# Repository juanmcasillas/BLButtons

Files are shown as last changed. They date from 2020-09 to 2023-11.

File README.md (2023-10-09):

# BLButtons
A simple, BLE Buttons controller to implement Simulator's button panels. Now supports multiple BLE profile,
you you map at the same time a Keyboard, a Gamepad and a Mouse.

Check this elements also:

* [ESP32-BLE-Combo](https://github.com/juanmcasillas/ESP32-BLE-Combo). Implements a multiple BLE profile, so you can send keyboard, mouse and gamepad (joystick) inputs as HID device.
* [BL-Radio](https://github.com/juanmcasillas/BLButtons/blob/master/RADIO.md). A custom made, generic radio panel (or whatever you want) to map the aircraft multiple radios interface. Implements modes and button remapping, as a bluetooth gamepad.
* [VoiceButtons](https://github.com/juanmcasillas/BLButtons/blob/master/voicebuttons/README.md). Map joystick inputs to text-to-speech commands. Works on Windows (Windows 10 tested) and includes a configuration file to tailor the app to your needs, and a DCS export module to extract data from it (so you can asign specific radio profiles por each mod (aka plane)). Very useful if you flight in VR and uses the `BL-Radio` radio panel.

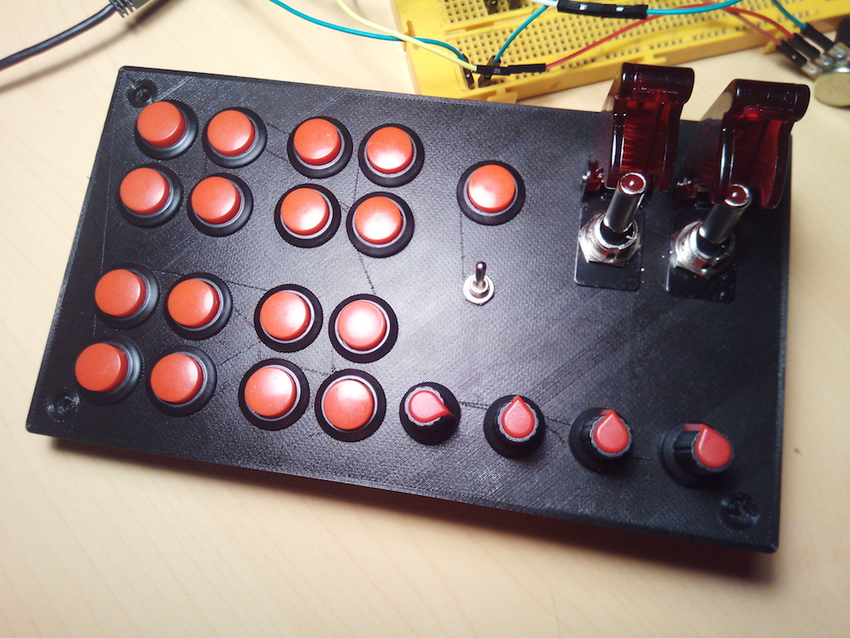
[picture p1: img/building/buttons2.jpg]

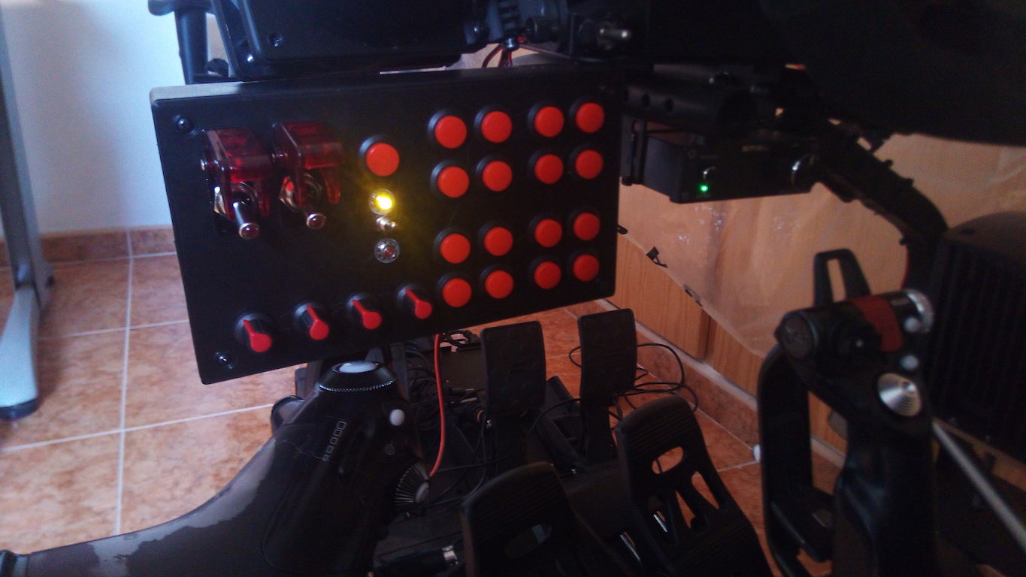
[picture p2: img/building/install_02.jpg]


# Table Of Contents

1. [Project Features](#project-features)

# Project Features

* Support clutch (2 modes).
* 4 axis x 3 = 12 axis (8 axis supported for Xinput).
* 17 buttons (x 2 modes) 51 buttons.
* 2 levers (two buttons) x 3 6 additional buttons.
* Pov hats are not in use.
* in clutch_mode == 2 (down), support for keyboard events (F1 ... F12) and mouse control.

* Changed the library [BLE Combo](https://github.com/Georgegipa/ESP32-BLE-Combo/) to support Gamepad. Use [My Fork](https://github.com/juanmcasillas/ESP32-BLE-Combo) in order to get the thing working.
## Arduino setup.

* Use [These drivers for the ESP32](https://www.silabs.com/developers/usb-to-uart-bridge-vcp-drivers?tab=downloads) on Win 10
* To upload, ensure the CLUTCH switch is on 0 (no light) or you can't upload the sketch.
* Use NodeMCU-32S (ESP32) board version to do the work

## ExceptionDecoder & SPIFFS Image Downloader

1. Go to [https://github.com/me-no-dev/EspExceptionDecoder/releases/](https://github.com/me-no-dev/EspExceptionDecoder/releases/) and download the latest release.
1. Go to [https://github.com/me-no-dev/arduino-esp32fs-plugin/releases/](https://github.com/me-no-dev/arduino-esp32fs-plugin/releases/) and download the latest release.
2. Go to the Arduino IDE directory, and open the `Tools` folder.
3. Unzip the downloaded .zip folders to the Tools folder. 
4. You should get something like `/Arduino-<version>/tools/ESP32FS/tool/esp32fs.jar` and the same for the exception decoder.

* [https://amstudioprojects.com/product/32-function-button-box-guide/](https://amstudioprojects.com/product/32-function-button-box-guide/)
* [https://www.instructables.com/id/Sim-Racing-Button-Box/](https://www.instructables.com/id/Sim-Racing-Button-Box/)
To use SPIFFS:

1. Inside the sketch folder, create a new folder called `data`
2. Inside the data folder is where you should put the files you want to be saved into the ESP32 filesystem.
3. Then, to upload the files, in the `Arduino IDE` you just need to go to `Tools > ESP32 Sketch Data Upload`.

Note: in some ESP32 development boards you need to keep the ESP32 on-board **`BOOT`** button pressed while it’s uploading the files. When you see the `Connecting …….____……` message, you need to press the ESP32 on-board **`BOOT`** button.

## BL gamepad library

0. Bounce2[https://github.com/thomasfredericks/Bounce2](https://github.com/thomasfredericks/Bounce2)
1. Go to [https://github.com/lemmingDev/ESP32-BLE-Gamepad/releases](https://github.com/lemmingDev/ESP32-BLE-Gamepad/releases) and download the latest release.
2. In the Arduino IDE go to `"Sketch" -> "Include Library" -> "Add .ZIP Library..."` and select the file you just downloaded.
3. You can now go to `"File" -> "Examples" -> "ESP32 BLE Gamepad"` and select the example to get started.
4. Updated to [https://github.com/MagnusThome/ESP32-BLE-Gamepad](https://github.com/MagnusThome/ESP32-BLE-Gamepad)
5. On laptop works properly.
6. A keypad Lib [https://github.com/Chris--A/Keypad](https://github.com/Chris--A/Keypad) for [The Example](https://github.com/MagnusThome/ESP32-BLE-Gamepad/blob/master/examples/5rotaryencoders_32buttons/5rotaryencoders_32buttons.ino)
7. Info about HID profile [https://eleccelerator.com/tutorial-about-usb-hid-report-descriptors/](https://eleccelerator.com/tutorial-about-usb-hid-report-descriptors/)
8. Official Nordic HID BLE [https://cdn.sparkfun.com/datasheets/Wireless/Bluetooth/RN-HID-User-Guide-v1.0r.pdf](https://cdn.sparkfun.com/datasheets/Wireless/Bluetooth/RN-HID-User-Guide-v1.0r.pdf)
9. Two profiles [https://www.esp32.com/viewtopic.php?t=10400](https://www.esp32.com/viewtopic.php?t=10400)
10. Keyboard HID profile [https://github.com/rupin/ESPJoystick/blob/master/gamepadble632/gamepadble632.ino](https://github.com/rupin/ESPJoystick/blob/master/gamepadble632/gamepadble632.ino)
11. USB HID definition tables [https://www.usb.org/hid](https://www.usb.org/hid)
12. USB HID usage tables [http://www.freebsddiary.org/APC/usb_hid_usages.php](http://www.freebsddiary.org/APC/usb_hid_usages.php)
13. More HID details [https://cdn.hackaday.io/files/18003770240352/HID.cpp](https://cdn.hackaday.io/files/18003770240352/HID.cpp)
14. Analog Smooth [https://github.com/MichaelThessel/arduino-analog-smooth](https://github.com/MichaelThessel/arduino-analog-smooth)
## Available PINOUTS

| GPIO | ADC  | INPUT | OUTPUT | NOTES |
|---|---|---|---|---:|
|0 x | 1/2  | pulled up | OK | Outputs PWM signal at boot |
|2 x | 2/2  | OK | OK | Connected to LED. LOW->LED Light  |
|4 x | 0/2  | OK | OK | |
|5 x | | OK | OK | Outputs PWM signal at boot |
|12 x | 5/2  | OK | OK | Boot fail if pulled HIGH |
|13 | 4/2  | OK | OK | Boot fail if pulled HIGH |
|14 x | 6/2  | OK | OK | Outputs PWM signal at boot |
|15 x | 2/2  | OK | OK | Outputs PWM signal at boot |
|16 x | | -- | -- | used on ESP-32_WROVER_KIT ** |
|17 x | | OK | OK | used on ESP-32_WROVER_KIT |
|18 x | | OK | OK | |
|19 x | | OK | OK | |
|21 | | OK | OK | |
|22 | | OK | OK | |
|23 | | OK | OK | |
|25 | 8/2  | OK | OK | |
|26 x | 9/2  | OK | OK | |
|27 x | 7/2  | OK | OK | |
|32 x | 4/1  | OK | OK | |
|33 x | 5/1  | OK | OK | |
|34 x | 6/1  | OK | | Input Only |
|35 x | 7/1  | OK | | Input Only |

* PIN16 on new version, doesn't work. Changed with PIN13
* ADC Column: ADC Channel/ADC1|ADC2. No number means no ADC.
* ADC2 pins cannot be used when Wi-Fi is used. 
* The ADC input channels have a 12 bit resolution. 
* This means that you can get analog readings ranging from 0 to 4095, in which 0 corresponds to 0V and 4095 to 3.3V. 
* ANALOG INPUTS: 14 . 10 on ADC2, 4 on ADC1 (usable with WIFI)
* DIGITAL INPUTS: 21 TOTAL, 7 only DIGITAL. Be careful with 12 and 13

* ANALOG -> 3 [18]
* KEYPAD -> 7x7 [14] [49 buttons] 
* Clutch -> 1 dedicated line (to avoid ghosting on the matrix - no use diodes)

## First Prototype

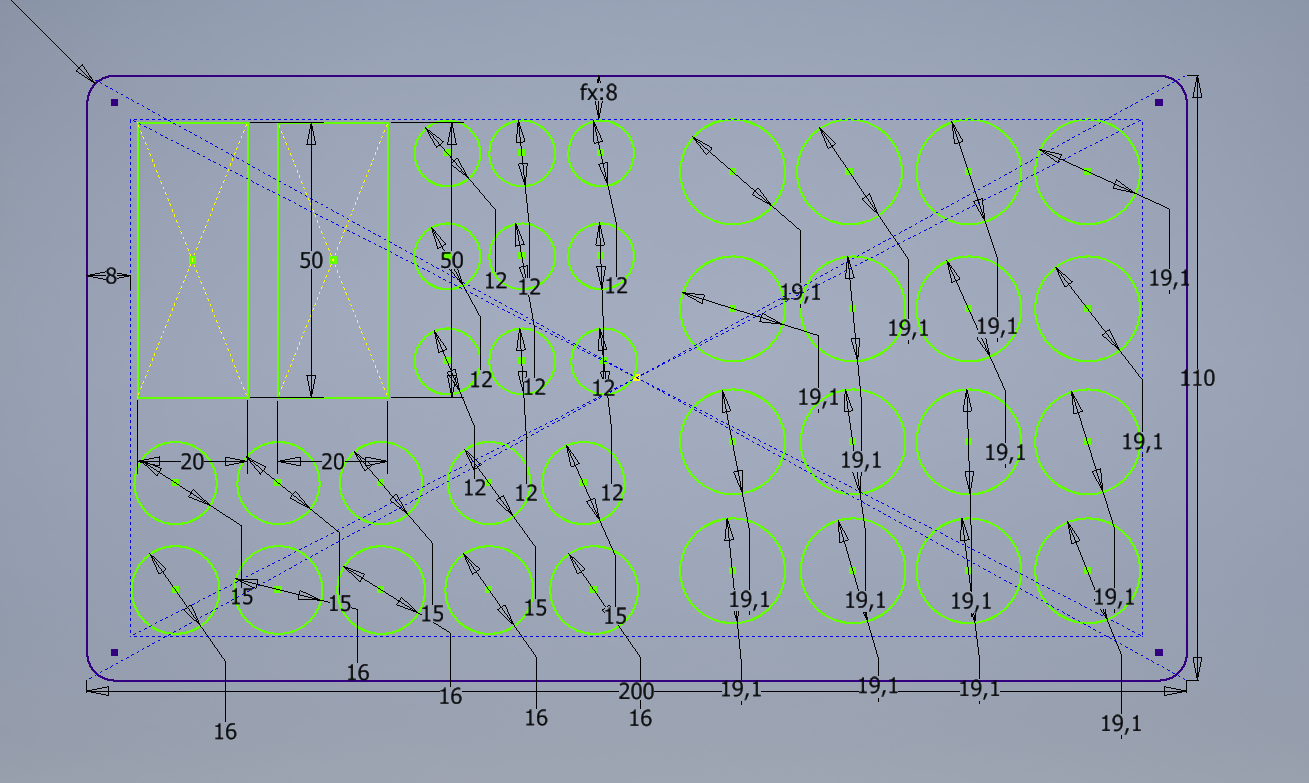
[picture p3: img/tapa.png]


```

| ITEM  |   QUANTITY    | PINS  | TOTAL PINS |
|-------|---------------|-------|-----------:|
|LEVC   | 2             | 1     |          2 |
|LEV    | 9             | 2     |         18 |
|BUT    | 16            | 1     |         16 |
|ENC    | 5             | 3     |         15 | 
|POT    | 5             | 1     |          5 |
|-------|---------------|-------|-----------:|
| TOTAL |               |       |  56 (51+5) |       
|-------|---------------|-------|-----------:|

MAX: 21 INPUTS

Clutch LEFT (+1 Digital) 57 (52+5)
ENC->Really are:
2 for DT*CLK signal
1 for SWITCH (serial plug)

-> More push buttons
-> Less Lever
-> Less Rotary (eats 3 pins per rotary)
*****Confirm these values****
Better more push buttons? (24)

4 pot (axis)    (21-4=17) [better 4 and leave the wifi alone]
4x4 = 16 buttons (17-(4+4)=9)
2LEVC (9-2=7)
CLUTCH (7-2=5)
2LEV (5-4=1)
1 free XD

| PIN   | TO                    | NOTES                |
|-------|-----------------------|---------------------:|
| 14    | COL_0                 | Boot Fail if HIGH    |
| 27    | COL_1                 |                      |
| 26    | COL_2                 |                      |
| 25    | COL_3                 |                      |
|-------|-----------------------|----------------------|
| 33    | POT_1 (leftmost)      | CH_4 ADC1 together   |
| 32    | POT_2                 | CH_5 ADC1            |
| 35    | POT_3                 | CH_6 ADC1            |
| 34    | POT_4 (rightmost)     | CH_7 ADC1            |
|-------|-----------------------|----------------------|
| 15    | CLUTCH_1              |                      |
| 2     | CLUTCH_2              | low or won't flash   |
|-------|-----------------------|----------------------|
| 4     | ROW_0                 | Pulled up            |
| 13    | ROW_1                 | Connected to LED (*) |
| 17    | ROW_2                 |                      |
| 5     | ROW_3                 | Boot Fail if HIGH    |
|-------|-----------------------|----------------------|
| 18    | LEVER_COVER_1         |                      |
|-------|-----------------------|----------------------|
| 19    | LEVER_COVER_2         |                      |
|-------|-----------------------|----------------------|
| 21    | BUTTON_1              |                      |
|-------|-----------------------|----------------------|
| 0     | free pins             | not use              |
| 2     |                       |                      | 
| 16    | in new version, fails | (*) changed with 13  |
| 22    |                       |                      |
| 23    |                       |                      |
|-------|-----------------------|----------------------|

Led Wiring: 300 OHMs resistor

MAX 32 inputs !!!
16 + 2 + 2 + 2 = 22 + 4 axis

CLUTCH mode:
    16 buttons x 2 = 32 inputs
    
BOX: 200x110x65
Lever: 74 x 54 x 12 mm
Lever_Cover: 60 x 130 x 40 mm

ENC:    15
POT:    16x25
BUT:    19
LEVC:   20x50
LEV:    12
```

## IL2 Minimum Controls

### Joystick 

Engine Start
Water Radiators 
Oil Radiators
Wheel Brake
Inlet/Outlet Cowls
Mixture
RPM lever (Prop pitch)
Flaps
Landing Gear
Open/Close Canopy
Open/Close Bomb Bay Doors
Airbrakes
Mission Brief Screen
Engine Boost
Fire Guns/Cannons/Missiles/Bombs
Auto Level
Field of view zoom in
Field of view zoom out
Recenter Track IR
Eject

### Keyboard

Nav Lights
Instrument Lights
Super Charger Stage Toggle
Engine Select

### The BLE profile (this has been changed due the combo mode)

```
 0x05, 0x01,              // USAGE_PAGE (Generic Desktop)
    0x09, 0x04,              // USAGE (Joystick)
    0xa1, 0x01,              // COLLECTION (Application)
    0x85, 0x03,              // REPORT_ID (3)
    0xa1, 0x00,              // COLLECTION (Physical)
    
    0x05, 0x09,              // USAGE_PAGE (Button)
    0x19, 0x01,              // USAGE_MINIMUM (Button 1)
    0x29, 0x40,              // USAGE_MAXIMUM (Button 64)
    0x15, 0x00,              // LOGICAL_MINIMUM (0)
    0x25, 0x01,              // LOGICAL_MAXIMUM (1)
    0x75, 0x01,              // REPORT_SIZE (1)
    0x95, 0x40,              // REPORT_COUNT (64)
    0x81, 0x02,              // INPUT (Data,Var,Abs)
    
    0xc0,               // END_COLLECTION
    0xc0               // END_COLLECTION
```

```
exports.report = new Uint8Array([
  0x05,   0x01,                    // USAGE_PAGE (Generic Desktop)
  0x09,   0x05,                    // USAGE (Game Pad) - Hut1_12v2.pdf p28 of 128
  0xA1,   0x01,                    // COLLECTION (Application)

  0xA1,   0x00,                    //   COLLECTION (Physical)
  0x05,   0x09,                    //     USAGE_PAGE (Button)
  0x19,   0x01,                    //     USAGE_MINIMUM (Button 1)
  0x29,   0x10,                    //     USAGE_MAXIMUM (Button 16)

  0x15,   0x00,                    //     LOGICAL_MINIMUM (0)
  0x25,   0x01,                    //     LOGICAL_MAXIMUM (1)
  0x95,   0x10,                    //     REPORT_COUNT (16)
  0x75,   0x01,                    //     REPORT_SIZE (1)

  0x81,   0x02,                    //     INPUT (Data,Var,Abs)

  0x05,   0x01,                    //     USAGE_PAGE (Generic Desktop)
  0x09,   0x30,                    //     USAGE (X)
  0x09,   0x31,                    //     USAGE (Y)
  0x09,   0x32,                    //     USAGE (Z) - Hut1_12v2.pdf p26 = represents R X-axis
  0x09,   0x33,                    //     USAGE (Rx) - Hut1_12v2.pdf p26 = represents R Y-axis

  0x15,   0x81,                    //     LOGICAL_MINIMUM (-127)
  0x25,   0x7F,                    //     LOGICAL_MAXIMUM (127)
  0x75,   0x08,                    //     REPORT_SIZE (8)
  0x95,   0x04,                    //     REPORT_COUNT (4)

  0x81,   0x06,                    //     INPUT (Data,Var,Abs) - absolute for joysticks ( != rel for mouse )
  0xC0,                            //   END_COLLECTION

  0xc0 ]                           // END_COLLECTION
);
```

NANO SERIAL: Solved using ATmega328P (Old Bootloader)...

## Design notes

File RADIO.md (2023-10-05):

# BL-Radio

Implement a generic radio control panel for DCS. Support multiple profiles, button mapping, and works as BLE wireless gamepad device. Now, support sending keypresses based on button mapping. The rationale is the OBS studio doesn't work
with DirectInput, so you can't map commands (start record, end record) to buttons what it's a pain. So due the the 
BLE combo stack supports multiple devices (keyboard, keypad, and mouse) I manage to double some buttons as keyboard
keypresses. if `KEYBOARD_CHORD` is defined, `KEY_RIGHT_ALT + KEY_RIGHT_CTRL` is also send to avoid keyboard collision.
see `KEYBOARD_MAP` array to map the desired keypresses to the buttons (keypress definitions are stored on `BleKeyboard.h`)

```
NANO 2W switches (top switches ath the sides of the selector box)

SW2_1_S1 ----> button 11 ---> Also doubles as keypress KEY_RIGHT_ALT + KEY_RIGHT_CTRL + KEYPAD_DIVIDE   (/ in keypad)
SW2_1_S2 ----> button 12 ---> Also doubles as keypress KEY_RIGHT_ALT + KEY_RIGHT_CTRL + KEYPAD_MULTIPLY (* in keypad)
SW2_2_S1 ----> button 13 ---> Also doubles as keypress KEY_RIGHT_ALT + KEY_RIGHT_CTRL + KEYPAD_SUBTRACT (- in keypad)
SW2_2_S2 ----> button 14 ---> Also doubles as keypress KEY_RIGHT_ALT + KEY_RIGHT_CTRL + KEYPAD_ADD      (+ in keypad)
```

<center>
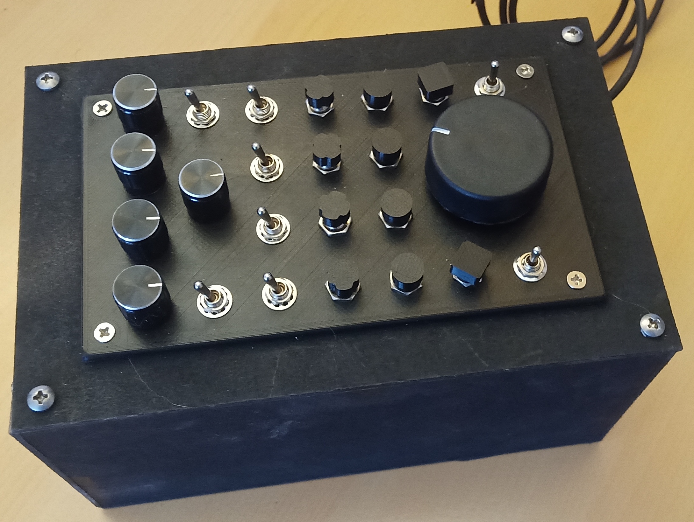
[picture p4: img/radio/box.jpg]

</br>
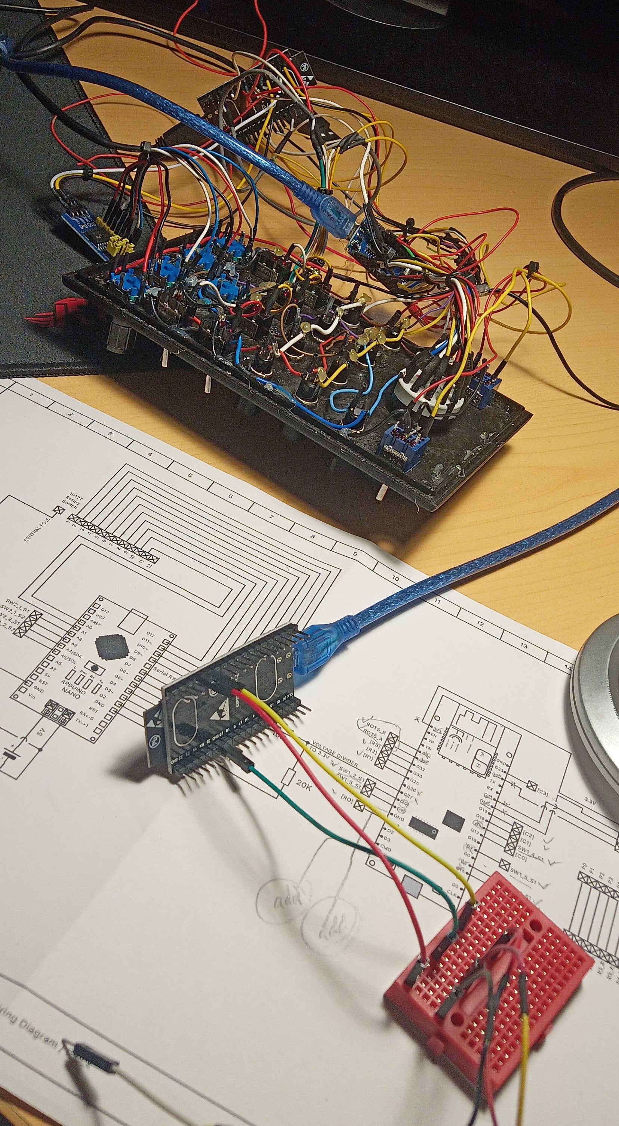
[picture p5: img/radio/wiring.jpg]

</center>

<center>
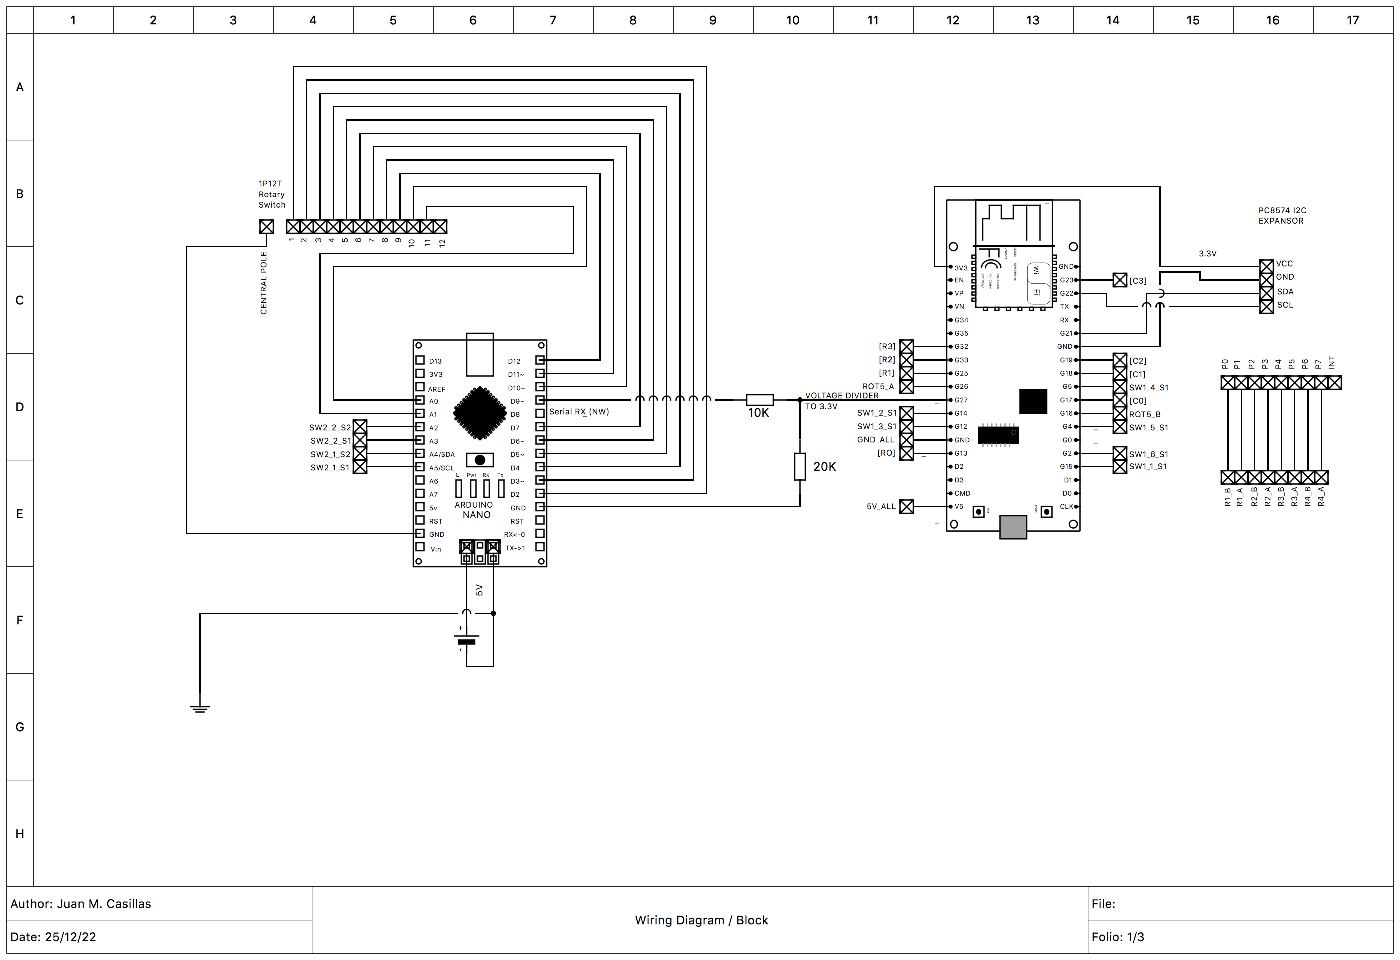
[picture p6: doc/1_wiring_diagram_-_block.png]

</br>
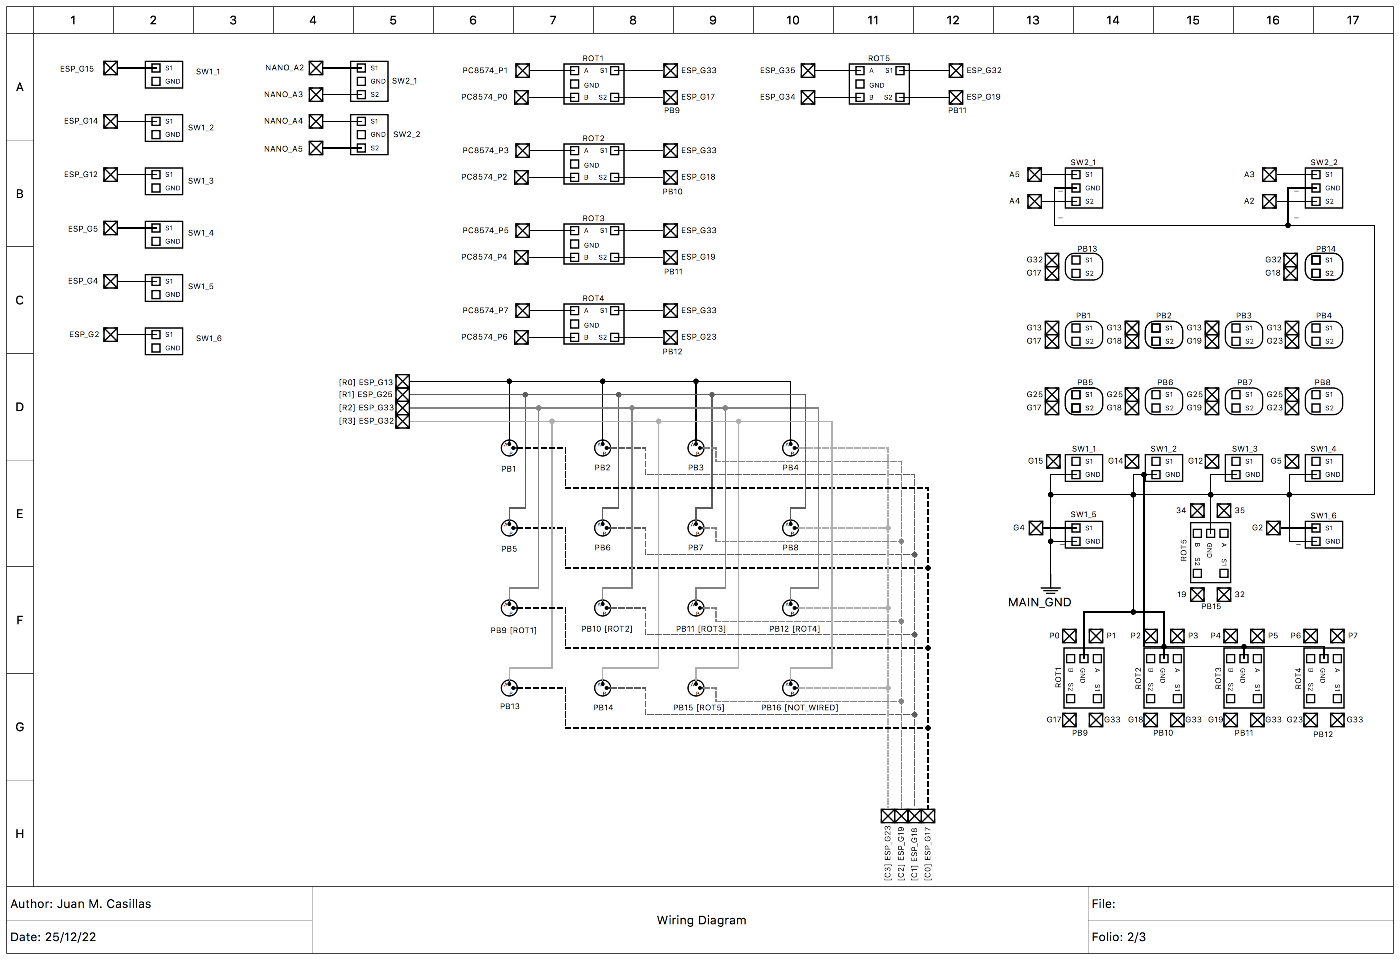
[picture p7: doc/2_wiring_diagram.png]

</br>
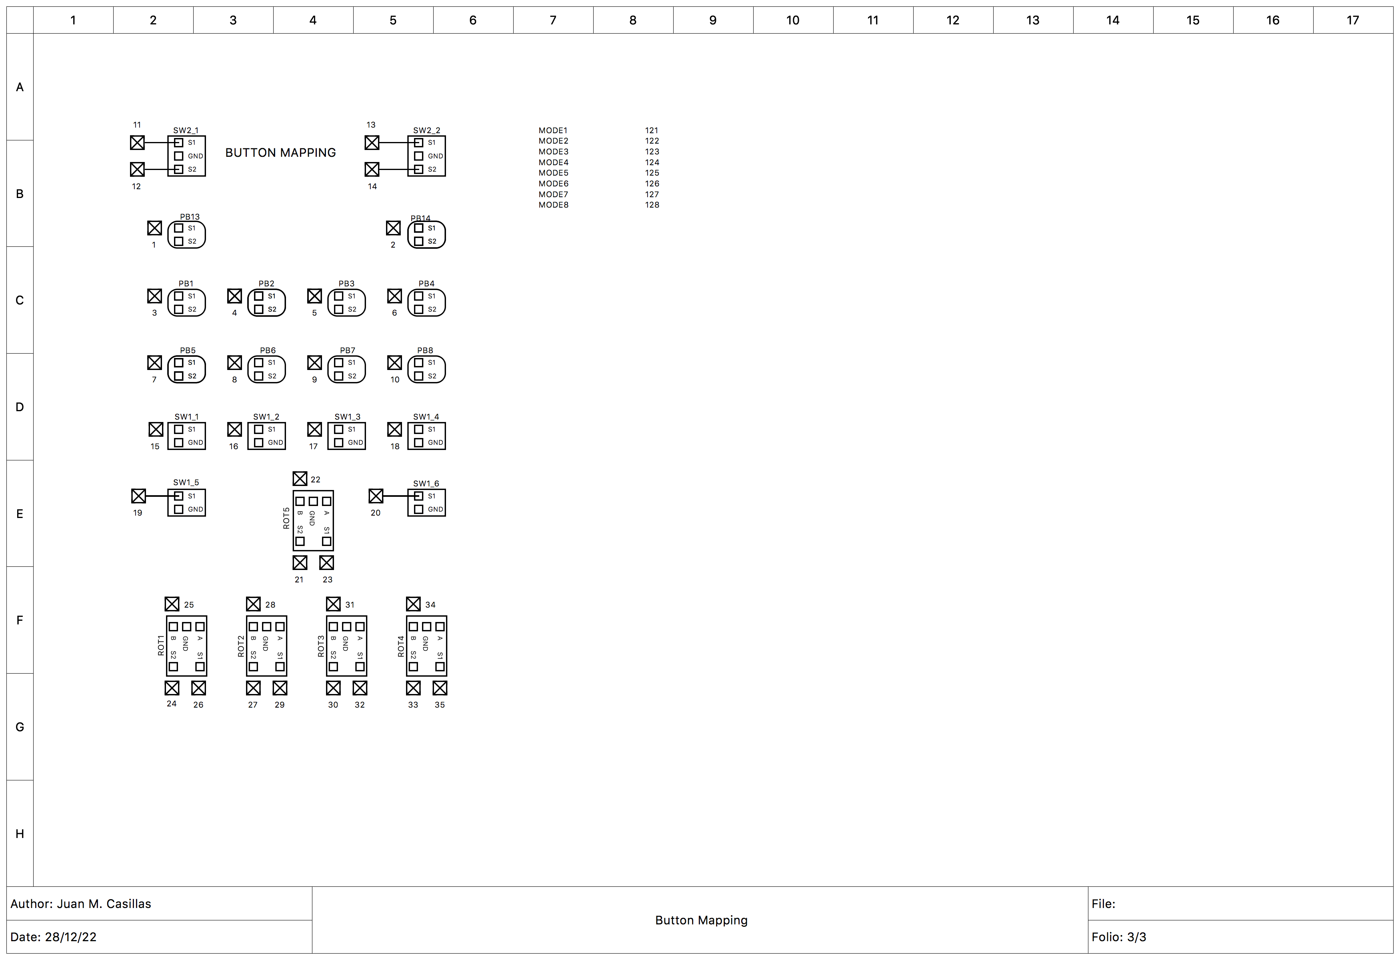
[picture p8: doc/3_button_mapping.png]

</center>

# 3D Printing files:

* <a href="stl/radio/tapa_radio.stl">Box Cover</a>
* <a href="stl/radio/button_round.stl">Button Round</a>
* <a href="stl/radio/button_square.stl">Button Square</a>
* <a href="stl/radio/button_round_variant.stl">Button Round (variant)</a>
* <a href="stl/radio/button_square_variant.stl">Button Square (variant)</a>

# Requirements

```
Lights:

   - taxi lights (left, right)
   - nav lights 
   - landing lights (left, right)
   - anti collision lights
   - formation lights
    
    - internal lights
    - dim 
    - center console
    - instruments
    - left console
    - right console
    - storm lights

F5
AN/ARC-164 UHF
    1 selector for channel preset
    5 selector for radio frequency tunning knobs
    1 mode (off, main, both, adf)
    1 freq mode (manual, preset, guard)
    1 selector antena (upper, auto, lower)

TACAN
    2 tunning knobs
    1 tacan mode: (off, t/r, a/a rec a/a t/r)
    1 nav_mode (df, tacan)

HSI
    1 knob for HDG
    1 knob for CRS

C101
ADF
    1 selector NAV/ADF (HSI)
    1 transfer button (to select adf1, adf2)
    3 kobs for ADF tunning
    1 selector for mode (off, ant, adf, test)
VOR (VHF-NAV)
    1 knob for tunning
    1 selector for mode (off, nav, stdby, dme, guard)
    1 selector antena (upper, auto, lower)
    1 dme hold or norm
VOR (ILS/AN/ARN-127)
    1 VHF 10 position selector (KHz) 105-117
    1 VHF 10 position selector (KHz) 0-9
    1 VHF 2 position selector (KHz) 00,05,

Huey
UHF AN/ARC-51BX (AA comms most used)
    1 function (off, t/r, t/r+g, adf)
    1 man/preset/gd-xmit
    1 select channel (1-20)
    3 dial knobs

VHF AN/ARC-134 (AA and Tower)
    1 function (off, power, test)
    2 dial knobs

FM AN/ARC-131 internal flight comms, ground homing
    1 function (off, t/r, retran,  home)
    4 dial knobs

AN/ARN-82 Radio Nav Panel
    1 selector (ADF, VOR)

AN/AR-83 ADF
    1 selector (off, adf, ant, loop)
    1 adf loop (left, right)
    1 bfo (on, off)
    1 adf band selector (3 pos)
    1 tunning knob
    1 adf gain
```

```
Pro MICRO inputs

ENCODERS:
    CLK         2x encoder D2/D3 se supone que se puede meter en un keypad.
    DT          
    SW          to the KEYPAD (button) + GND
    VCC (+)     common
    GND         common

5 encoders:
    2 (CLK,DT) x 5 = 10 signals + 5 SW = 15 (4x4) = 16 inputs. left 1.

Selectors & switches.
    3 position
    1 radio selector 8 pos (better 6)
    7 ?

Resume:

ENCODERS:
2 PINs PER encoder: 8 PINS for input encoding.

Encoders:                            =  4 + 8 PINS.
Encoder 1P12T using 12T              = 12
5 three way switch (using 2)         = 10            (10)
5 two way switch (using 1)           =  5            (7)
5 buttons                            =  5            (5 black, 5 red)
TOTAL                                = 36 input.

6x6 = 36 matrix.

Buttons:
  Encoders: 3 * 4 =       12
  3-way: 5 x 2 =          10
  2-way: 5 x 1 =           5
  5 buttons: 5 x 1 =       5
  TOTAL                   32 buttons.
  Modes (12): 12 x 32=    384 buttons (3x128 buttons) (gamepad device with 3 pages ? XD)

https://github.com/RobTillaart/PCF8574/issues/27

3 x 3 -> 9 buttons (5 buttons + 4 encoders)

1 expansor para los switches de 3 vias (8 inputs) 0x1
1 expansor para los switches de 2 vias + 1 de tres vias (8 inputs) 0x2
1 expansor para los encoders (4 * 2) 8 inputs.
2 + 6 = 8 PINS.
```

| PIN | TO | NOTES |
|---|---|---:|
Button matrix: 9 values, 3x3 matrix
| 13    | COL_0                 |                      |
| 14    | COL_1                 | Boot Fail if HIGH    |
| 27    | COL_2                 |                      |
| 26    | ROW_0                 |                      |
| 25    | ROW_1                 |                      |
| 33    | ROW_2                 | CH_4 ADC1 together   |
| MODE_SELECTOR = 12 values, 3x4 matrix
| 4     | ROW_0                 | Pulled up            |
| 16    | ROW_1                 | Connected to LED     |
| 17    | ROW_2                 |                      |
| 18    | COL_0                 |                      |
| 19    | COL_1                 |                      |
| 23    | COL_2                 |                      |
| 32    | COL_3                 | CH_5 ADC1            |
| maybe use the 5th element.
| 15    | ENCODER_5 SW          |                      |
| 34    | ENCODER_5 DT          | CH_7 ADC1 only IN    | 
| 35    | ENCODER_5 CLK         | CH_6 ADC1 only IN    |
| --
| 21    | SDA                   |                      |
| 22    | SCL                   |                      |
| --
| 2     |                       | low or won't flash   | 
| 5     |                       | Boot Fail if HIGH    |
| 12    |                       |                      | 
| --
|       | free pins             |                      |
| --
| --
| 0     |                       | not use              |
| --

```
LAST CALCULATION.
Buttons must be momentary in order to work with the KEYPAD.

So:
  Mode selector: 12 input keypadtrix 3*4 = 12 signals. (7 GPIO)
  5 3-way: (10 signals, using 8 in one expansor I2C using 2 in the other expansor.
  6 2-way: (6 signals, using 6 in the second expansor)
  5 encoders: 
        - 1x4 signals in a keypad arrangement of 3x3 GPIO (6 GPIO) 
        - 2x4 signals in the third expansor (8 signals)

        - 1x1 signal in the GPIO 2 (SW)
        - 2x1 signals in GPIO5, and 12.

TOTALS:
  1x  Mode:           12 signals, 4x3, 7 GPIO.
  5x  3-way:          10 signals, 2 GPIO (SCL,SDA)
  6x  2-way:           6 signals
  5x  encoders: SW:    4 signals in the keypad button, 3x3, 6 GPIO
             CLK/DT    8 signals in the third expansor
             SW:       1 signal on GPIO2
             CLK/DT    2 signals on GPIO5, GPIO12
  5x buttons:          5 signals in the keypad button.
```

## after implementing the Serial bridge between Arduino Nano & ESP32

```
So:
  Mode selector: 12 Signals from 15 available using GPIO27,GPIO26 [3 available, frees 4 GPIO[4,16,17,18,19,23,32], used on Serial]
  5 3-way: (10 signals, using 8 in one expansor I2C using 2 in the other expansor.
  6 2-way: (6 signals, using 6 in the second expansor)
  6 encoders: 
        - 1x6 signals in a keypad arrangement of 4x4 
        - 2x4 signals in the third expansor (8 signals) CLK/DT
        - 4x1 signals in GPIO5, GPIO12, 

  1x  Mode:           12 signals, 2 GPIO [Serial]
  6x  3-way:          10 signals, 2 GPIO (SCL,SDA)
                       2 signals, 2 GPIO [Serial]
  6x  2-way:           6 signals
  6x  encoders: SW:       6 signals in the keypad button, 4x4, 8 GPIO
                CLK/DT    8 signals in the third expansor (SCL,SDA)
                CLK/DT    2 signals on GPIO5, GPIO12
                CLK/DT    2 signals on GPI23, GPIO32
  6x buttons:          6 signals in the keypad button.

                       ?? 1 signal 2 GPIO available [Serial]
                       ?? 4 signal available on keypad.
  4 free gpios mean instead 3x3 (9) 4x4 (16) -> 7 more buttons !!! [13,14]
```

## After getting al the components:

| PIN | TO | NOTES |
|---|---|---:|
| Button matrix: 16 values, 4x4 matrix
| 13 | ROW_0 | |
| 25 | ROW_1 | |
| 33 | ROW_2 | CH_4 ADC1 together |
| 32 | ROW_3 | CH_5 ADC1 |
| 17 | COL_0 | |
| 18 | COL_1 | |
| 19 | COL_2 | |
| 23 | COL_3 | |
| MODE_SELECTOR = 12 values, 12 signals, 2 GPIO [Serial]
| 27 | RX | |
| 26 | TX | |
| Expansors I2C
| 21 | SDA | |
| 22 | SCL | |
| 2 |  2W | low or won't flash | 
| 4 |  2W | Pulled up |
| 5 |  2W | Boot Fail if HIGH |
| 12 |  2W | cant be pulled HIGH  | 
| 14 |  2W | Boot Fail if HIGH |
| 15 |  2W | |
| Extra encoders 
| 34 | | CH_7 ADC1 only IN | 
| 35 | | CH_6 ADC1 only IN |
| free pins
| 0 | | not use |
| maybe use the 5th element.
| 16 | 2W | Connected to LED |

```
  Mode selector: 11 Signals from 15 available using GPIO27,GPIO26Serial]
  2 3-way in nano. (4 signals) [only 2 values]
  6 2-way ESP32 [2,4,5,12,14,15]
  4 encoders in the expansor (8 signals)
  1 encoder in ESP32 [34,35]

  5 buttons from encoders [left 11 buttons]
  6 push buttons [on keypad matrix]
  
  Rotary encoder
  
   CW
 (right)  
    ^     A    ---+----+
    |             |    +--- PIN 
    |     GND  ---+    |
    |             |    +--- GND
    v     B    ---+----+

  CCW 
 (left)
  
  Rotary switch

  central pole = GND
  external poles = PINS

  Mode selector: 11 Signals from 15 available using GPIO27,GPIO26 [4 available, frees 4 GPIO[4,16,17,18,19,23,32], used on Serial]
  5 3-way: (10 signals, using 8 in one expansor I2C using 2 in the other expansor.
  6 2-way: (6 signals, using 6 in the second expansor)
  5 encoders: 
        - 1x3 signals in the NANO GPIO27,GPIO26

        [- 1x5 signals in a keypad arrangement of 4x4  ?]
        - 2x4 signals in the third expansor (8 signals) CLK/DT
        - 4x1 signals in GPIO5, GPIO12, 

  1x  Mode:           11 signals, 2 GPIO [Serial]
  6x  3-way:          10 signals, 2 GPIO (SCL,SDA)
                       2 signals, 2 GPIO [Serial]
  6x  2-way:           6 signals
  5x  encoders: SW:       4 signals in the keypad button, 4x4, 8 GPIO [¿?] 5 SIGNALS
                CLK/DT    8 signals in the third expansor (SCL,SDA)
                CLK/DT    2 signals on GPIO5, GPIO12
                CLK/DT    2 signals on GPI23, GPIO32
  6x buttons:          6 signals in the keypad button.

                       ?? 1 signal 2 GPIO available [Serial]
                       ?? 4 signal available on keypad.

```

* https://github.com/AM-STUDIO/32-FUNCTION-BUTTON-BOX/blob/master/ARDUINO_BUTTON_BOXV2.ino
* https://forum.arduino.cc/t/sketch-para-cinco-encoders-con-promicro/994954
* https://www.youtube.com/watch?v=Z7Sc4MJ8RPM

```
//BUTTON BOX 
//USE w ProMicro

#include <Keypad.h>
#include <Joystick.h>

#define ENABLE_PULLUPS
#define NUMROTARIES 4
#define NUMBUTTONS 24
#define NUMROWS 5
#define NUMCOLS 5

byte buttons[NUMROWS][NUMCOLS] = {
  {0,1,2,3,4},
  {5,6,7,8,9},
  {10,11,12,13,14},
  {15,16,17,18,19},
  {20,21,22,23},
};

struct rotariesdef {
  byte pin1;
  byte pin2;
  int ccwchar;
  int cwchar;
  volatile unsigned char state;
};

rotariesdef rotaries[NUMROTARIES] {
  {0,1,24,25,0},
  {2,3,26,27,0},
  {4,5,28,29,0},
  {6,7,30,31,0},
};

#define DIR_CCW 0x10
#define DIR_CW 0x20
#define R_START 0x0

#ifdef HALF_STEP
#define R_CCW_BEGIN 0x1
#define R_CW_BEGIN 0x2
#define R_START_M 0x3
#define R_CW_BEGIN_M 0x4
#define R_CCW_BEGIN_M 0x5
const unsigned char ttable[6][4] = {
  // R_START (00)
  {R_START_M,            R_CW_BEGIN,     R_CCW_BEGIN,  R_START},
  // R_CCW_BEGIN
  {R_START_M | DIR_CCW, R_START,        R_CCW_BEGIN,  R_START},
  // R_CW_BEGIN
  {R_START_M | DIR_CW,  R_CW_BEGIN,     R_START,      R_START},
  // R_START_M (11)
  {R_START_M,            R_CCW_BEGIN_M,  R_CW_BEGIN_M, R_START},
  // R_CW_BEGIN_M
  {R_START_M,            R_START_M,      R_CW_BEGIN_M, R_START | DIR_CW},
  // R_CCW_BEGIN_M
  {R_START_M,            R_CCW_BEGIN_M,  R_START_M,    R_START | DIR_CCW},
};
#else
#define R_CW_FINAL 0x1
#define R_CW_BEGIN 0x2
#define R_CW_NEXT 0x3
#define R_CCW_BEGIN 0x4
#define R_CCW_FINAL 0x5
#define R_CCW_NEXT 0x6

const unsigned char ttable[7][4] = {
  // R_START
  {R_START,    R_CW_BEGIN,  R_CCW_BEGIN, R_START},
  // R_CW_FINAL
  {R_CW_NEXT,  R_START,     R_CW_FINAL,  R_START | DIR_CW},
  // R_CW_BEGIN
  {R_CW_NEXT,  R_CW_BEGIN,  R_START,     R_START},
  // R_CW_NEXT
  {R_CW_NEXT,  R_CW_BEGIN,  R_CW_FINAL,  R_START},
  // R_CCW_BEGIN
  {R_CCW_NEXT, R_START,     R_CCW_BEGIN, R_START},
  // R_CCW_FINAL
  {R_CCW_NEXT, R_CCW_FINAL, R_START,     R_START | DIR_CCW},
  // R_CCW_NEXT
  {R_CCW_NEXT, R_CCW_FINAL, R_CCW_BEGIN, R_START},
};
#endif

byte rowPins[NUMROWS] = {21,20,19,18,15}; 
byte colPins[NUMCOLS] = {14,16,10,9,8}; 

Keypad buttbx = Keypad( makeKeymap(buttons), rowPins, colPins, NUMROWS, NUMCOLS); 

Joystick_ Joystick(JOYSTICK_DEFAULT_REPORT_ID, 
  JOYSTICK_TYPE_JOYSTICK, 32, 0,
  false, false, false, false, false, false,
  false, false, false, false, false);

void setup() {
  Joystick.begin();
  rotary_init();}

void loop() { 

  CheckAllEncoders();

  CheckAllButtons();

}

void CheckAllButtons(void) {
      if (buttbx.getKeys())
    {
       for (int i=0; i<LIST_MAX; i++)   
        {
           if ( buttbx.key[i].stateChanged )   
            {
            switch (buttbx.key[i].kstate) {  
                    case PRESSED:
                    case HOLD:
                              Joystick.setButton(buttbx.key[i].kchar, 1);
                              break;
                    case RELEASED:
                    case IDLE:
                              Joystick.setButton(buttbx.key[i].kchar, 0);
                              break;
            }
           }   
         }
     }
}

void rotary_init() {
  for (int i=0;i<NUMROTARIES;i++) {
    pinMode(rotaries[i].pin1, INPUT);
    pinMode(rotaries[i].pin2, INPUT);
    #ifdef ENABLE_PULLUPS
      digitalWrite(rotaries[i].pin1, HIGH);
      digitalWrite(rotaries[i].pin2, HIGH);
    #endif
  }
}

unsigned char rotary_process(int _i) {
   unsigned char pinstate = (digitalRead(rotaries[_i].pin2) << 1) | digitalRead(rotaries[_i].pin1);
  rotaries[_i].state = ttable[rotaries[_i].state & 0xf][pinstate];
  return (rotaries[_i].state & 0x30);
}

void CheckAllEncoders(void) {
  for (int i=0;i<NUMROTARIES;i++) {
    unsigned char result = rotary_process(i);
    if (result == DIR_CCW) {
      Joystick.setButton(rotaries[i].ccwchar, 1); delay(50); Joystick.setButton(rotaries[i].ccwchar, 0);
    };
    if (result == DIR_CW) {
      Joystick.setButton(rotaries[i].cwchar, 1); delay(50); Joystick.setButton(rotaries[i].cwchar, 0);
    };
  }
}
```

## Voltage divider for TX with ESP32

First off all, we need to do a voltage adaptation from 5V to 3.3V in ESP:

```
                                                                                    x-G26<-ESP32 [Serial TX]
                                                +------------------------------------>G27<-ESP32 [Serial RX]
                                                |                      +------------->GND<-ESP32
                                                |                      |              
[SERIAL TX] NANO->D9------------5V--->[R10K]----x--3.3V--[R20K]------>GND
[SERIAL RX] NANO->D8-x                                                 |
                                                                       |
[D12 INPUT] NANO->D12---------------->[ PUSH BUTTON ]------------------+
[D11 INPUT] NANO->D11---------------->[ PUSH BUTTON ]------------------+
[D10 INPUT] NANO->D10---------------->[ PUSH BUTTON ]------------------+
                                                                       |
            NANO->GND--------------------------------------------------|
```

## Wiring information

```
                                                                                    
ARDUINO NANO
Serial port with voltage divider
                                                                  x-G26<-ESP32 [Serial TX] Not connected
                                                +------------------>G27<-ESP32 [Serial RX]
                                                |                     
                                                |                                 
NANO->D9------------5V--->[R10K]----x--3.3V--[R20K]------>GND
NANO->D8-x                                                 |
                                                           |
                                                           |
NANO->GND--------------------------------------------------+

Rotary switch 1P12T
NANO->D2--------------------------------------------------------------1<-1P12T
NANO->D3--------------------------------------------------------------2<-1P12T
NANO->D4--------------------------------------------------------------3<-1P12T
NANO->D5--------------------------------------------------------------4<-1P12T
NANO->D6--------------------------------------------------------------5<-1P12T
NANO->D7--------------------------------------------------------------6<-1P12T
NANO->D10-------------------------------------------------------------7<-1P12T
NANO->D11-------------------------------------------------------------8<-1P12T
NANO->D12-------------------------------------------------------------9<-1P12T
NANO->A0-------------------------------------------------------------10<-1P12T
NANO->A1-------------------------------------------------------------11<-1P12T
                                                                   x-12<-1P12T [Not connected]
NANO->GND--------------------------------------------------------CENTER<-1P12T

2W (2 Way switches)

NANO->A2-------------------------------------------------------------S2<-2W [2]
NANO->A3-------------------------------------------------------------S1<-2W
NANO->A4-------------------------------------------------------------S2<-2W [1]
NANO->A5-------------------------------------------------------------S1<-2W

Power input for external power source
NANO->ICSP->GND
NANO->ICSP->VCC (5V)

ESP32
ESP32->G26->x                                                                       (Serial TX) Not connected 
ESP32->G26-----------------------------------------------------------D9<-NANO       (Serial RX) See NANO diagram

1-way Switches (S1_)
ESP32->G2------------------------------------------------------------S1<-SW1_6
ESP32->G4------------------------------------------------------------S1<-SW1_5
ESP32->G5------------------------------------------------------------S1<-SW1_4
ESP32->G12-----------------------------------------------------------S1<-SW1_3
ESP32->G14-----------------------------------------------------------S1<-SW1_2
ESP32->G15-----------------------------------------------------------S1<-SW1_1

I2c to PC8574 Expansor
ESP32->3V3-----------------------------------------------------------SCL<-VCC
ESP32->GND-----------------------------------------------------------SCL<-GND
ESP32->G22-----------------------------------------------------------SCL<-PC8574
ESP32->G21-----------------------------------------------------------SDA<-PC8574

KeyPad Grid

ESP32->G13-----------------------------------------------------------ROW_0
ESP32->G25-----------------------------------------------------------ROW_1
ESP32->G33-----------------------------------------------------------ROW_2
ESP32->G32-----------------------------------------------------------ROW_3

ESP32->G17-----------------------------------------------------------COL_0
ESP32->G18-----------------------------------------------------------COL_1
ESP32->G19-----------------------------------------------------------COL_2
ESP32->G23-----------------------------------------------------------COL_3

Extra encoder
ESP32->G34-----------------------------------------------------------B<-ROT_5
ESP32->G35-----------------------------------------------------------A<-ROT_5

PC8574
PC8574->P0-----------------------------------------------------------B<-ROT1
PC8574->P1-----------------------------------------------------------A<-ROT1
PC8574->P2-----------------------------------------------------------B<-ROT2
PC8574->P3-----------------------------------------------------------A<-ROT2
PC8574->P4-----------------------------------------------------------B<-ROT3
PC8574->P5-----------------------------------------------------------A<-ROT3
PC8574->P6-----------------------------------------------------------B<-ROT4
PC8574->P7-----------------------------------------------------------A<-ROT4
PC8574->INT-x
```

## To use 2.0.5 core instead 1.0.6

* Only can use 1.0.6 due the rest is compiling from 2.x.x (mac os 10.14 >)
* https://docs.espressif.com/projects/arduino-esp32/en/latest/installing.html
* https://raw.githubusercontent.com/espressif/arduino-esp32/gh-pages/package_esp32_index.json
* https://dl.espressif.com/dl/package_esp32_index.json
* http://arduino.esp8266.com/stable/package_esp8266com_index.json

## i2c addresses

```
// 32 (0x20)
// default jumper connection:
// 32 (0x20) address
// x x x
// x x x
// | | | 
// x x x
//A0   A2
//
// 33 (0x21) address
// x x x
// |
// x x x
//   | | 
// x x x
//A0   A2
//
// 35 (0x23) address
// x x x
// | |
// x x x
//     |  
// x x x
//A0   A2
//
// our working example
//
// 35 (0x23) address
// x x x
// | |
// x x x
//     |  
// x x x
//A0   A2
//
```

## Note about serial sync and power up simultaneously

* Arduino delay(100) on setup() (before)
* ESP32 delay(500) on setup() (after)

if not done so, the serial port doesn't work.

## How to change the windows name for the device.

* If you plan to use two devices in the same pc, you must change
* this values (e.g. BL-Radio & BL-Buttons)
* Look in device manager for the Bluetooh -> BL-Combo or BL-Radio.
* right click, Children, point the Dev_VID&02bd05_PID&02b82_REV&1202
*  these are the values we put on BLCombo:h: 
  
```
  uint16_t vid = 0x05bd;
  uint16_t pid = 0x820b;
  uint16_t version = 0x0212;
```

* Issue a regedit and look for "8 axis" or look for VIDBD05 [see the pattern]
* Then under Joystick->OEM->VIDBD05&PID_0B82 Change OEMName to desired one.

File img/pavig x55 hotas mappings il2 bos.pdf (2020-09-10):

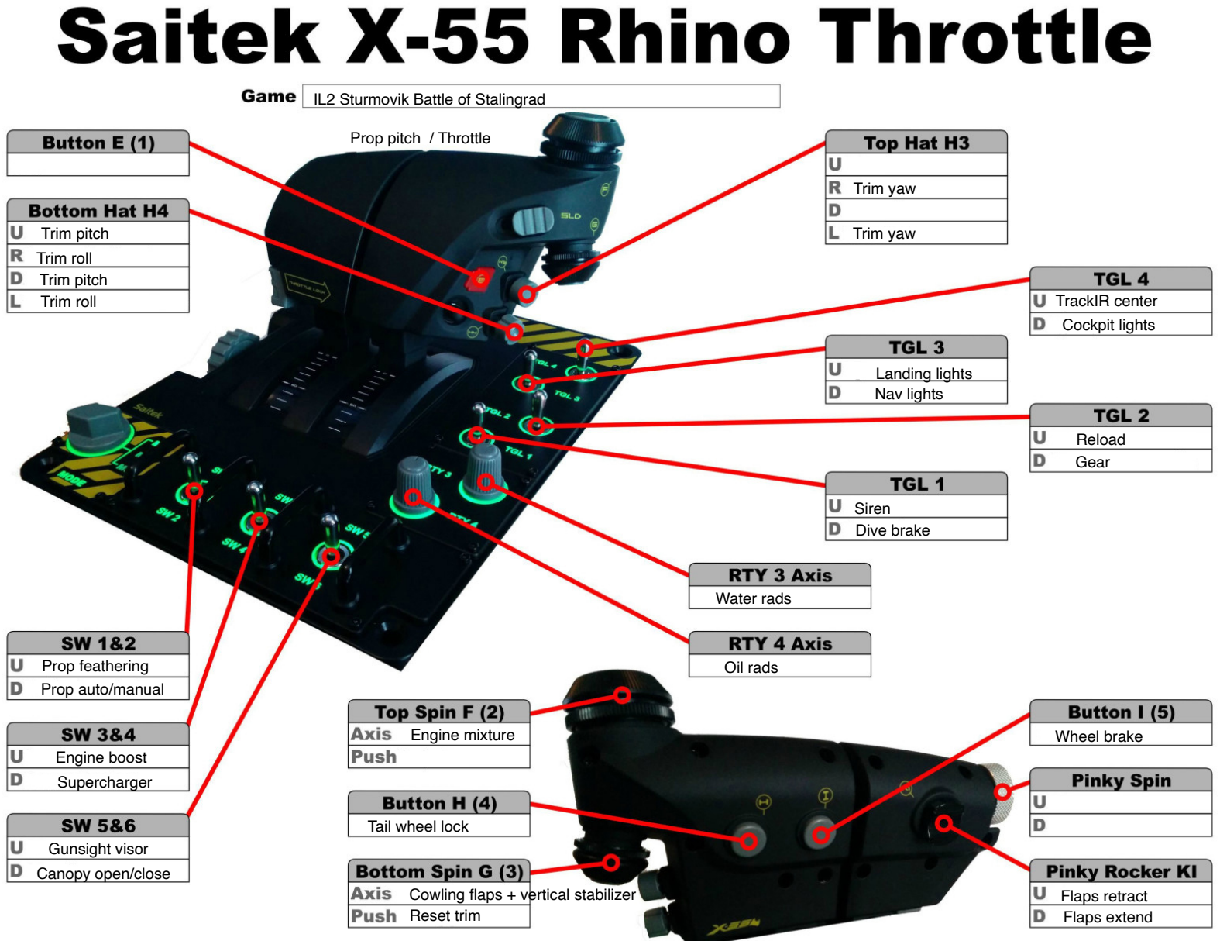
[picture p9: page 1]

Reset trim

Cowling flaps + vertical stabilizer

Water rads

Oil rads

Trim pitch
Trim roll
Trim pitch
Trim roll

Trim yaw

Trim yaw

TrackIR center
Cockpit lights

Landing lights
Nav lights

Gear

Supercharger

Engine boost

Wheel brake

Tail wheel lock

Flaps retract
Flaps extend

Engine mixture

Prop auto/manual

Prop feathering

Canopy open/close

Gunsight visor

IL2 Sturmovik Battle of Stalingrad

Prop pitch / Throttle

Siren
Dive brake

Reload

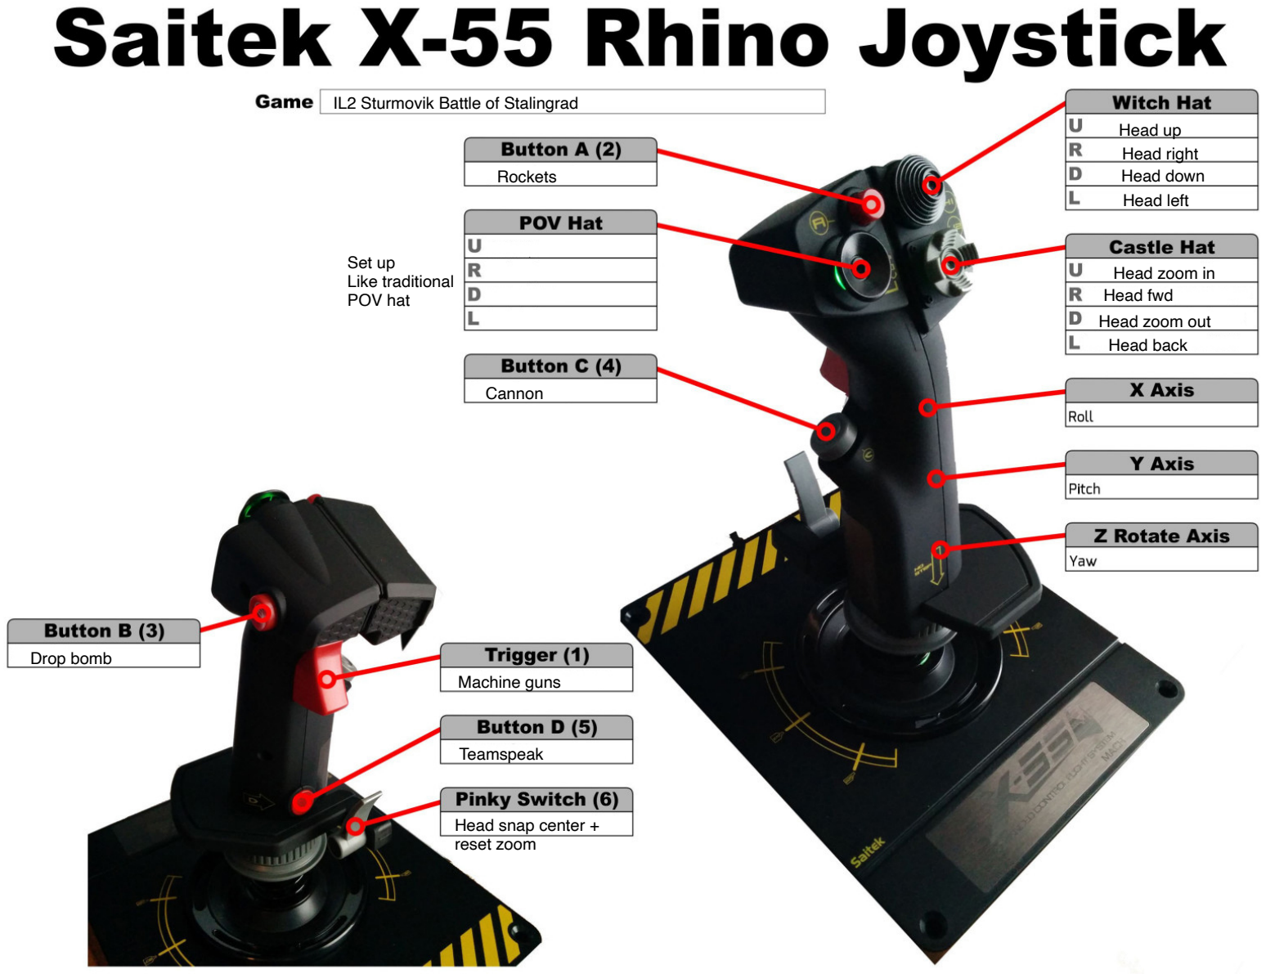
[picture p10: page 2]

IL2 Sturmovik Battle of Stalingrad

Head zoom out

Head zoom in

Head snap center +
reset zoom

Teamspeak

Drop bomb
Machine guns

Cannon

Rockets

Head fwd

Head back

Head up
Head right
Head down
Head left

Set up
Like traditional
POV hat

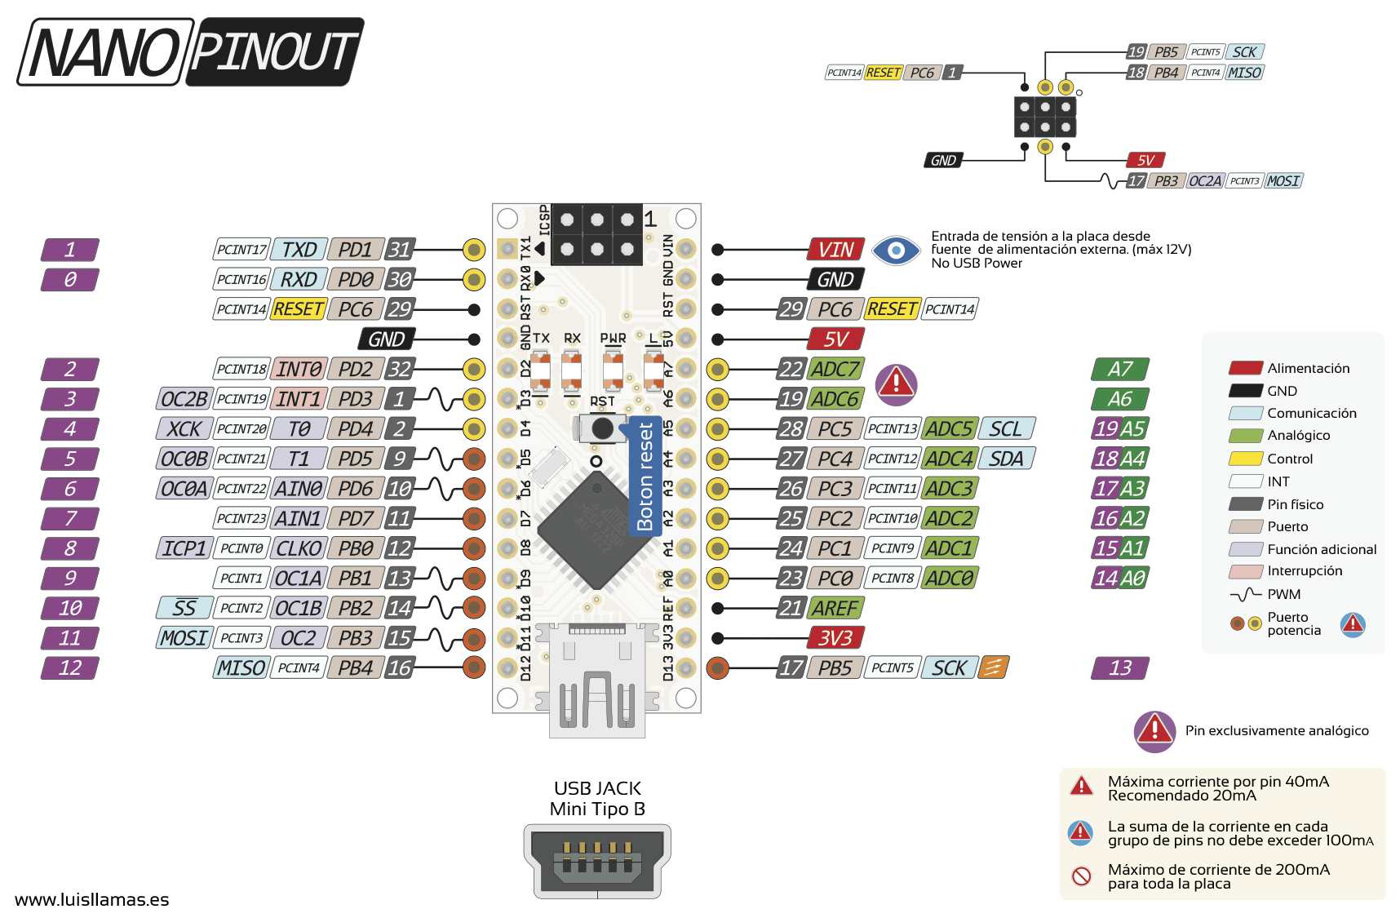
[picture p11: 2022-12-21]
img/aduino-pinout-nano.png

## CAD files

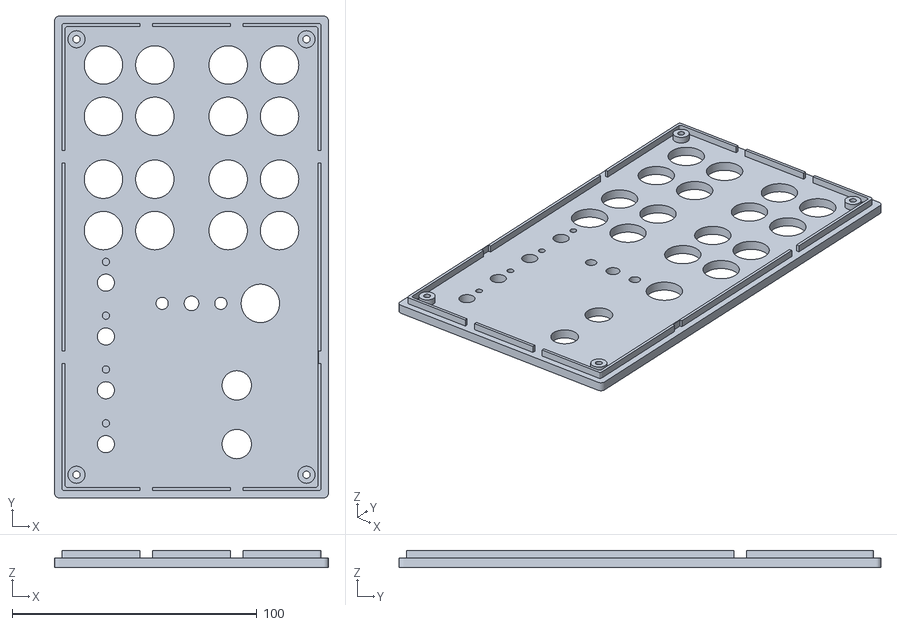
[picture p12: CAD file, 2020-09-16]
stl/cover.stl
112.0 x 197.0 x 7.00

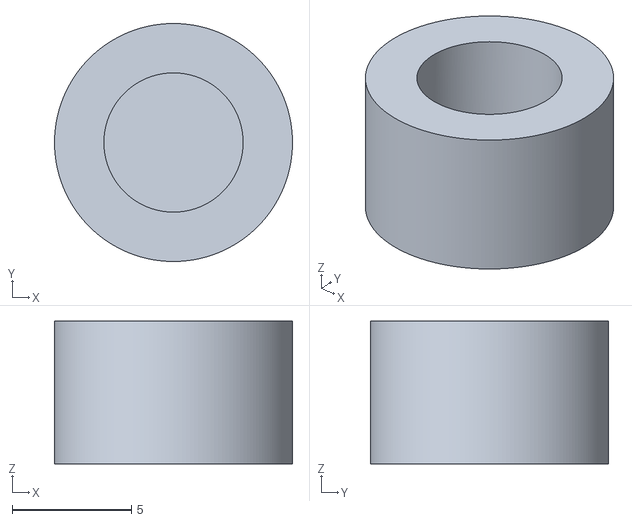
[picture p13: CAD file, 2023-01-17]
stl/radio/button_round.stl
10.0 x 10.0 x 6.00

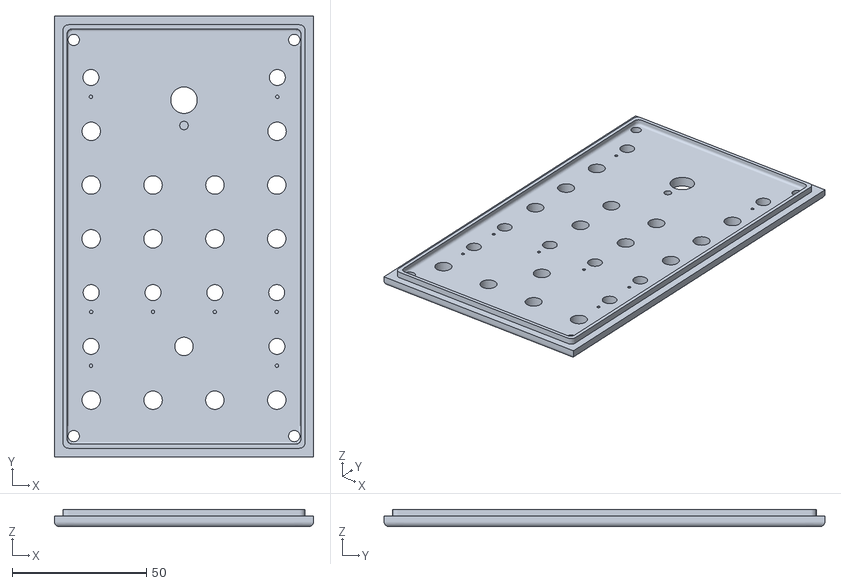
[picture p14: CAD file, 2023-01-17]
stl/radio/tapa_radio.stl
96.5 x 164.0 x 6.50

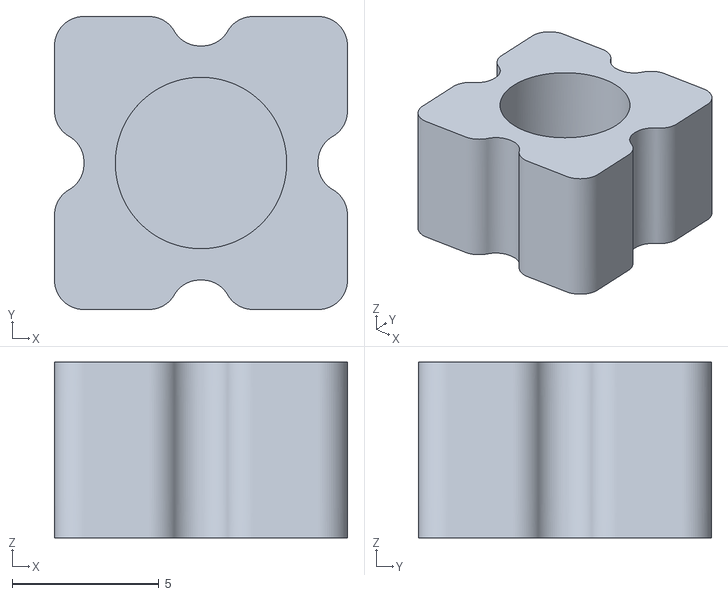
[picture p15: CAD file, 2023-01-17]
stl/radio/button_square_variant.stl
10.0 x 10.0 x 6.00

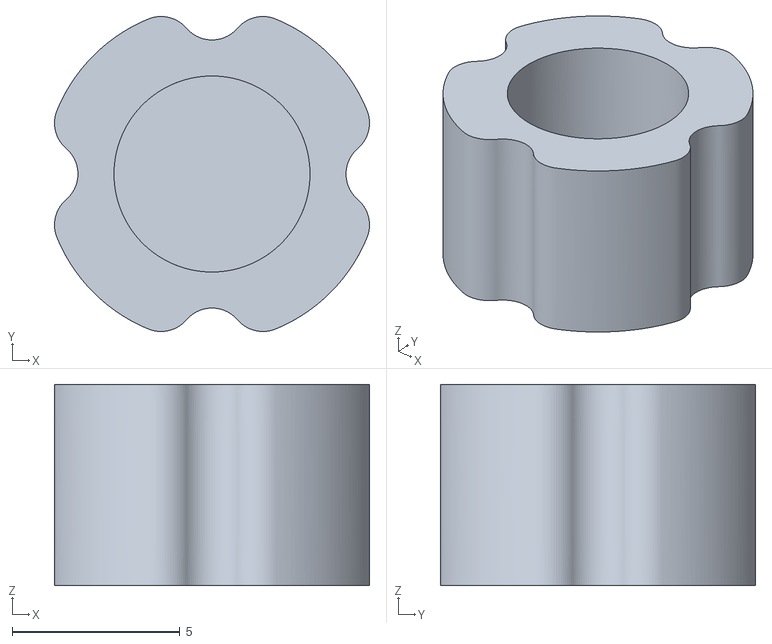
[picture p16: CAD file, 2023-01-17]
stl/radio/button_round_variant.stl
9.40 x 9.40 x 6.00

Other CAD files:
stl/radio/button_square.stl

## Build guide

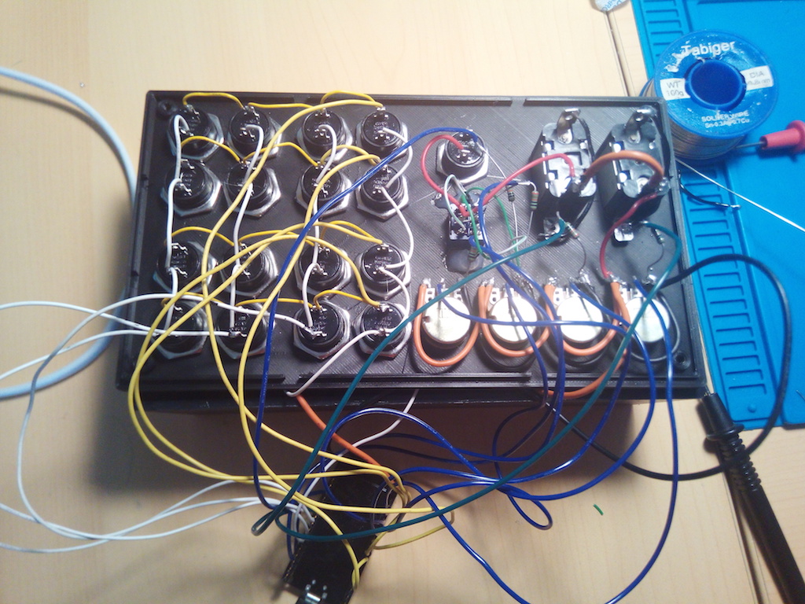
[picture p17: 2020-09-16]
img/building/back_wiring_03.jpg

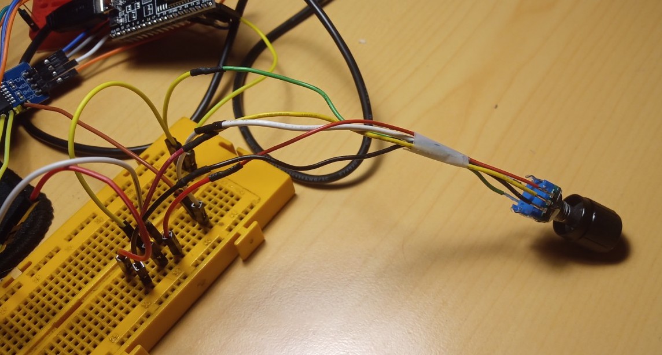
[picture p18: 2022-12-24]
img/rotary_wiring.jpg

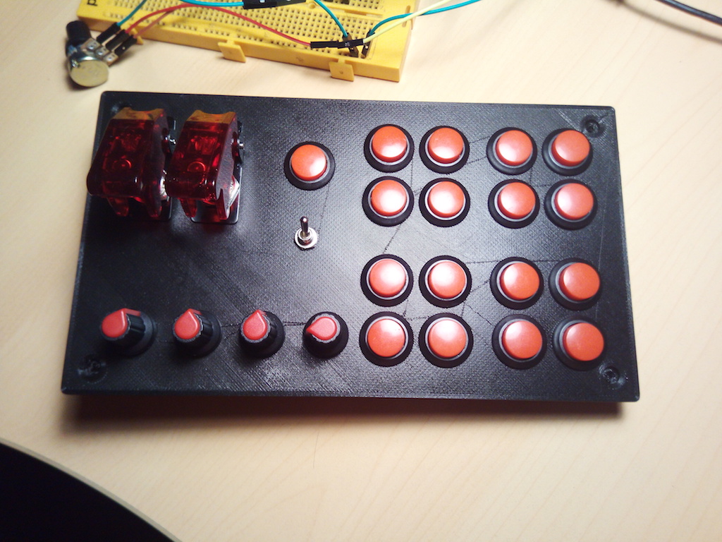
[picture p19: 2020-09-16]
img/building/buttons.jpg

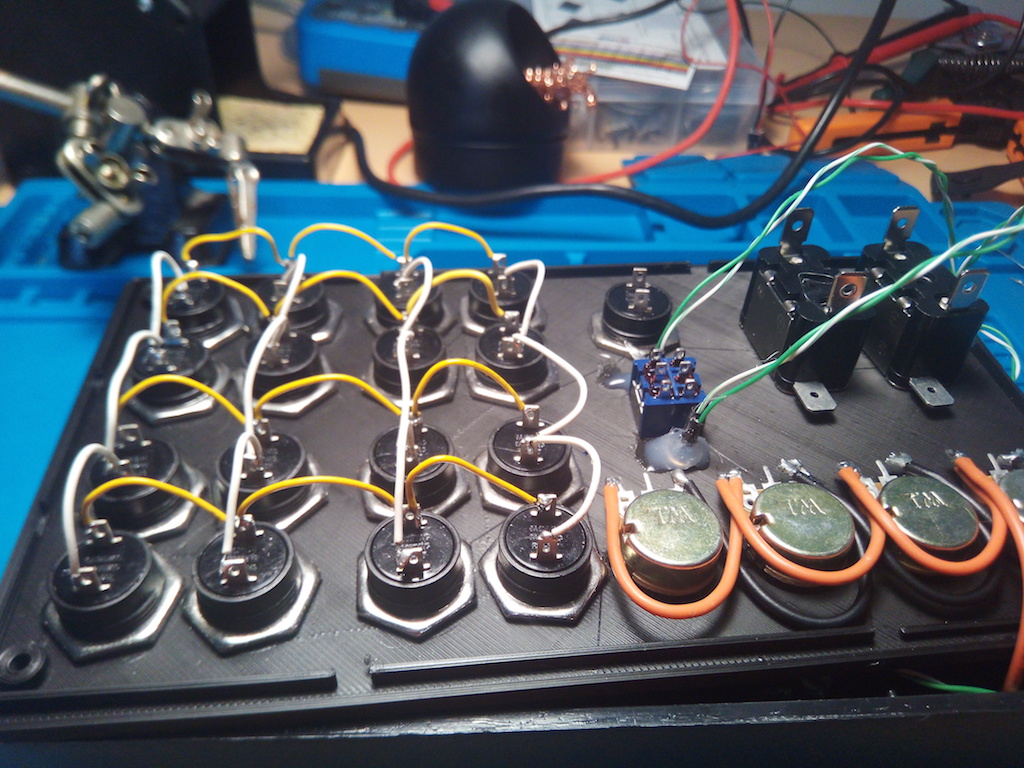
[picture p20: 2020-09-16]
img/building/back_wiring_02.jpg

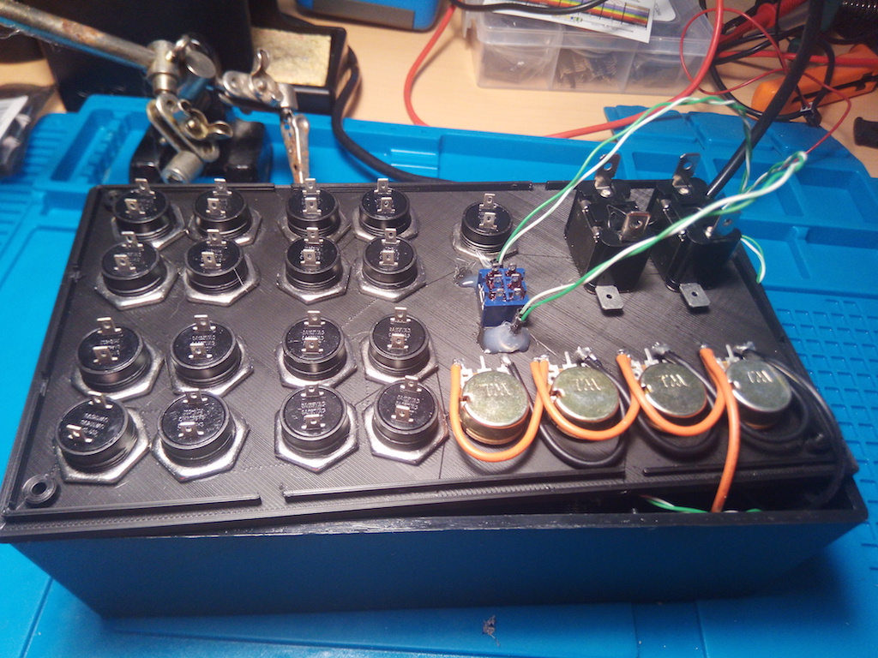
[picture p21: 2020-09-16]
img/building/back_wiring_01.jpg

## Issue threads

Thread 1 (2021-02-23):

can we add _ENCODER_h or some else to support rotry encoders?

MRWZJP, 2021-02-23:
sorry , i am noob, i just have this idea. XD

juanmcasillas, 2021-03-09:
Hello!

Yes, rotary support can be added without problem.

Kind Regards

Closed 2021-03-09.

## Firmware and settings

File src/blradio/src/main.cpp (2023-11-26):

//////////////////////////////////////////////////////////////////////////////
///
/// @file i2cenc.ino
/// @author Juan M. Casillas (juanm.casillas@gmail.com)
/// @brief test the PCF8574 and encoder lib
/// @version 0.1
/// @date 2022/12/22
///
/// Code to test the PCF8574 expansor and some features.
/// P0 is the pin nearest the address jumpers.
/// 
/// @copyright Copyright (c) 12/22/2022 Juan M. Casillas <juanm.casillas@gmail.com>
///
//////////////////////////////////////////////////////////////////////////////
//
// PCF8574
// 
// https://www.luisllamas.es/mas-pines-digitales-con-arduino-y-el-expansor-es-i2c-pcf8574/
// use this https://github.com/xreef/PCF8574_library/releases
// https://github.com/khoih-prog/ESP32TimerInterrupt
//

// define this to support multiple keyscan press (see below)
// #define ENABLE_KEYBOARD_MAP 1
#define RELEASE 1                 /* define this to remove all debug data */
#define DEBUG_SERIAL  0x1
#define DEBUG_SIGNALS 0x2
#define DEBUG_BUTTON  0x4
#define DEBUG_STATE   0x8
#define DEBUG_KEYS   0x10
#define DEBUG_ROTENC 0x20
#define DEBUG_ALL    0xFF
// #define DEBUG DEBUG_ALL
// #define DEBUG DEBUG_SERIAL | DEBUG_BUTTON
// #define DEBUG DEBUG_SERIAL | DEBUG_SIGNALS               /* define this to debug extra info */
// #define TESTING 1                                        /* undefine this to use the real BL stack. Clean All and build */


// see helpers.h for debug defines

#include <Arduino.h>
#include <PCF8574.h>            // https://github.com/xreef/PCF8574_library
#include <Ticker.h>
#include <HardwareSerial.h>
#include <Keypad.h>             // https://github.com/Chris--A/Keypad
    
#include <BleKeyboard.h>        // https://github.com/juanmcasillas/ESP32-BLE-Combo
#include <BleMouse.h>           // https://github.com/juanmcasillas/ESP32-BLE-Combo
#include <BleGamepad.h>         // https://github.com/juanmcasillas/ESP32-BLE-Combo

#include "rotencoder.h"
#include "bltools.h"



// 
// PIN DEFINITIONS
//

#define PIN_LED     2
// pins for the extra rotary encoder
#define PIN_ROT5_A 16
#define PIN_ROT5_B 26

// pins for the serial port (only use the TX)
#define PIN_SERIAL_RX 27
#define PIN_SERIAL_TX 26

// pins for the 1-way switches
#define PIN_SW1_1_S1 15
#define PIN_SW1_2_S1 14
#define PIN_SW1_3_S1 12
#define PIN_SW1_4_S1 5
#define PIN_SW1_5_S1 4
#define PIN_SW1_6_S1 2

// Keypad row & col PINS
#define PIN_KP_ROW_0 13
#define PIN_KP_ROW_1 25
#define PIN_KP_ROW_2 33
#define PIN_KP_ROW_3 32

#define PIN_KP_COL_0 17
#define PIN_KP_COL_1 18
#define PIN_KP_COL_2 19
#define PIN_KP_COL_3 23

//
// use the pin definitions for each service.
//

#define PIN_RX PIN_SERIAL_RX
#define PIN_TX PIN_SERIAL_TX

#define ROT5_PINA PIN_ROT5_A
#define ROT5_PINB PIN_ROT5_B // THE SAME as PIN_TX (see setup())

//
// define the signals that comes from the NANO via serial port
//
#define S_1P12T_1    0
#define S_1P12T_2    1
#define S_1P12T_3    2
#define S_1P12T_4    3
#define S_1P12T_5    4
#define S_1P12T_6    5
#define S_1P12T_7    6
#define S_1P12T_8    7
#define S_1P12T_9    8
#define S_1P12T_10   9
#define S_1P12T_11  10

#define S_SW2_1_S1  11
#define S_SW2_1_S2  12
#define S_SW2_2_S1  13
#define S_SW2_2_S2  14

//
// maps the position on BUTTONS (bits) to signals
//
//
// maps the position on BUTTONS (bits) to signals
//
unsigned char NANO_BITS[] {
    2,    //S_1P12T_1 
    3,    //S_1P12T_2 
    4,    //S_1P12T_3 
    5,    //S_1P12T_4 
    6,    //S_1P12T_5 
    7,    //S_1P12T_6 
   10,    //S_1P12T_7 
   11,    //S_1P12T_8 
   12,    //S_1P12T_9 
   14,    //S_1P12T_10
   15,    //S_1P12T_11
   16,    //S_SW2_2_S2 // bad wiring
   17,    //S_SW2_2_S1 // bad wiring
   18,    //S_SW2_1_S2 // bad wiring
   19     //S_SW2_1_S1 // bad wiring
};

//
// ESP 1way Switches
//
#define S_SW1_1_S1  15  // G15
#define S_SW1_2_S1  16  // G14
#define S_SW1_3_S1  17  // G12
#define S_SW1_4_S1  18  // G5
#define S_SW1_5_S1  19  // G4
#define S_SW1_6_S1  20  // G2

//
// define the keypad signals.
//
#define S_KP_1   21
#define S_KP_2   22
#define S_KP_3   23
#define S_KP_4   24
#define S_KP_5   25
#define S_KP_6   26
#define S_KP_7   27
#define S_KP_8   28
#define S_KP_9   29
#define S_KP_10  30
#define S_KP_11  31
#define S_KP_12  32
#define S_KP_13  33
#define S_KP_14  34
#define S_KP_15  35
#define S_KP_16  36



//
// rotary definitions
//
#define MAX_ROTARIES 5
RotaryEncoder *encoders[MAX_ROTARIES];
#define ROT1    0
#define ROT2    1
#define ROT3    2
#define ROT4    3
#define ROT5    4
#define ROT_LEFT  0
#define ROT_RIGHT 1

//
// define the rotary encoders buttons [left, right]
//
#define S_ROT_1_LEFT  37
#define S_ROT_1_RIGHT 38
#define S_ROT_2_LEFT  39
#define S_ROT_2_RIGHT 40
#define S_ROT_3_LEFT  41
#define S_ROT_3_RIGHT 42
#define S_ROT_4_LEFT  43
#define S_ROT_4_RIGHT 44
#define S_ROT_5_LEFT  45
#define S_ROT_5_RIGHT 46

unsigned char rotenc_map[MAX_ROTARIES][2] = {
    { S_ROT_1_LEFT, S_ROT_1_RIGHT },
    { S_ROT_2_LEFT, S_ROT_2_RIGHT },
    { S_ROT_3_LEFT, S_ROT_3_RIGHT },
    { S_ROT_4_LEFT, S_ROT_4_RIGHT },
    { S_ROT_5_LEFT, S_ROT_5_RIGHT },
};

// 
// define the signals for the mode selector
//

#define S_MODE_1      47
#define S_MODE_2      48
#define S_MODE_3      49
#define S_MODE_4      50
#define S_MODE_5      51
#define S_MODE_6      52
#define S_MODE_7      53
#define S_MODE_8      54
#define MAX_MODES      8

unsigned char mode_map[MAX_MODES] = {
    S_MODE_1,
    S_MODE_2,
    S_MODE_3,
    S_MODE_4,
    S_MODE_5,
    S_MODE_6,
    S_MODE_7,
    S_MODE_8
};

//
// keypad matrix.
//
#define KP_ROWS 4
#define KP_COLS 4
uint8_t kp_rowPins[KP_ROWS] = {PIN_KP_ROW_0, PIN_KP_ROW_1, PIN_KP_ROW_2, PIN_KP_ROW_3};
uint8_t kp_colPins[KP_COLS] = {PIN_KP_COL_0, PIN_KP_COL_1, PIN_KP_COL_2, PIN_KP_COL_3};

uint8_t keymap[KP_ROWS][KP_COLS] = {
    { 6,  5,   4,  3},
    {10,  9,   8,  7},
    {15,  14, 13, 12},
    { 2,  1,  11, 16}   // 16 last one not phisically connected.
};
Keypad customKeypad = Keypad(makeKeymap(keymap), kp_rowPins, kp_colPins, KP_ROWS, KP_COLS);

uint8_t keymap_signals[] = {
    0,      // not used, only for aligment
    S_KP_1  ,
    S_KP_2  ,
    S_KP_3  ,
    S_KP_4  ,
    S_KP_5  ,
    S_KP_6  ,
    S_KP_7  ,
    S_KP_8  ,
    S_KP_9  ,
    S_KP_10 ,
    S_KP_11 ,   // rotenc 5
    S_KP_12 ,   // rotenc 4
    S_KP_13 ,   // rotenc 3
    S_KP_14 ,   // rotenc 2
    S_KP_15 ,   // rotenc 1
    S_KP_16 // not used
};

// 
// signal container
//
#define MAX_SIGNALS 56
unsigned char SIGNALS[MAX_SIGNALS]      = { 0 };
unsigned char PREV_SIGNALS[MAX_SIGNALS] = { 0 };

// 
// data (single serial byte)
//
uint8_t DATA;



// max buttons: 35 
// rotenc = 15 buttons. (12 counting only the last row)
#define LAST_FIXED_BUTTON 23 // the last button of the non movable buttons
unsigned char BUTTON_MAP[] = {
//
// NANO MODE.
// this is used as a mode selector, not a button
// so don't map it here. The number is the button
// number. 0 means no button, just for reference
// to map the table usign the signal ID.
//

0, // S_1P12T_1
0, // S_1P12T_2
0, // S_1P12T_3
0, // S_1P12T_4
0, // S_1P12T_5
0, // S_1P12T_6
0, // S_1P12T_7
0, // S_1P12T_8
0, // S_1P12T_9
0, // S_1P12T_10
0, // S_1P12T_11

// 
// NANO two way switches
//
11, // S_SW2_1_S1
12, // S_SW2_1_S2
13, // S_SW2_2_S1
14, // S_SW2_2_S2

// 
// ESP 32 one way switches
//

15, // S_SW1_1_S1
16, // S_SW1_2_S1
17, // S_SW1_3_S1
18, // S_SW1_4_S1 
20, // S_SW1_6_S1  // bad wiring
19, // S_SW1_5_S1 

//
// buttons
//
1,  // S_KP_1   
2,  // S_KP_2   
3,  // S_KP_3   
4,  // S_KP_4   
5,  // S_KP_5   
6,  // S_KP_6   
7,  // S_KP_7   
8,  // S_KP_8   
9,  // S_KP_9   
10, // S_KP_10

22, // S_KP_11     // ROT5
25, // S_KP_12     // ROT1
28, // S_KP_13     // ROT2
31, // S_KP_14     // ROT3
34, // S_KP_15     // ROT4

0, // S_KP_16     // not used.

//
// rotenc buttons (left, right)
// 

33, // S_ROT_4_LEFT  
35, // S_ROT_4_RIGHT 
30, // S_ROT_3_LEFT  
32, // S_ROT_3_RIGHT 
27, // S_ROT_2_LEFT  
29, // S_ROT_2_RIGHT 
24, // S_ROT_1_LEFT  
26, // S_ROT_1_RIGHT 
21, // S_ROT_5_LEFT  
23, // S_ROT_5_RIGHT

// 
// the mode selector now sends buttons
// FIRST_MODE_BUTTON to avoid mapping over

121, // S_MODE_1
122, // S_MODE_2
123, // S_MODE_3
124, // S_MODE_4
125, // S_MODE_5
126, // S_MODE_6
127, // S_MODE_7
128  // S_MODE_8

};

//
// create a keyboard map. If the signal is mapped here (!= 0)
// then invoke the keypress using the keyboard interface.
// useful for multiple keymapping (you know, obs)
// define ENABLE_KEYBOARD_MAP for support this (see top)



// if keyboard chord is enabled, keys are send with
// to avoid overlapping. Chord can be only 2 keys
// KEY_RIGHT_ALT + KEY_RIGHT_CTRL + KEY
#define KEYBOARD_CHORD 1

unsigned char KEYBOARD_MAP[] = {
0, // S_1P12T_1
0, // S_1P12T_2
0, // S_1P12T_3
0, // S_1P12T_4
0, // S_1P12T_5
0, // S_1P12T_6
0, // S_1P12T_7
0, // S_1P12T_8
0, // S_1P12T_9
0, // S_1P12T_10
0, // S_1P12T_11
KEYPAD_DIVIDE, // S_SW2_1_S1 mapped to signal 11 (position=11) mapped to KEYPAD_DIVIDE      // this is position 11 (signal == 11)
KEYPAD_MULTIPLY, // S_SW2_1_S2 mapped to signal 12 (position=12) mapped to KEYPAD_MULTIPLY  // this is position 12 (signal == 12)
KEYPAD_SUBTRACT, // S_SW2_2_S1 mapped to signal 13 (position=13) mapped to KEYPAD_SUBTRACT  // this is position 13 (signal == 13)
KEYPAD_ADD, // S_SW2_2_S2 mapped to signal 14 (position=14) mapped to KEYPAD_ADD            // this is position 14 (signal == 14)
0, // S_SW1_1_S1
0, // S_SW1_2_S1
0, // S_SW1_3_S1
0, // S_SW1_4_S1 
0, // S_SW1_6_S1  // bad wiring
0, // S_SW1_5_S1 
0,  // S_KP_1   
0,  // S_KP_2   
0,  // S_KP_3   
0,  // S_KP_4   
0,  // S_KP_5   
0,  // S_KP_6   
0,  // S_KP_7   
0,  // S_KP_8   
0,  // S_KP_9   
0, // S_KP_10
0, // S_KP_11     // ROT5
0, // S_KP_12     // ROT1
0, // S_KP_13     // ROT2
0, // S_KP_14     // ROT3
0, // S_KP_15     // ROT4
0, // S_KP_16     // not used.
0, // S_ROT_4_LEFT  
0, // S_ROT_4_RIGHT 
0, // S_ROT_3_LEFT  
0, // S_ROT_3_RIGHT 
0, // S_ROT_2_LEFT  
0, // S_ROT_2_RIGHT 
0, // S_ROT_1_LEFT  
0, // S_ROT_1_RIGHT 
0, // S_ROT_5_LEFT  
0, // S_ROT_5_RIGHT
0, // S_MODE_1
0, // S_MODE_2
0, // S_MODE_3
0, // S_MODE_4
0, // S_MODE_5
0, // S_MODE_6
0, // S_MODE_7
0  // S_MODE_8
};


#define FIRST_MODE_BUTTON 121


uint8_t SELECTOR;                // manages the state of the central selector (helpers.h)
uint8_t PREV_SELECTOR;

Ticker periodicTicker;
#define DELAY_TIME 50           // time to wait in the loop()
#define EXPANDER_ADDESS 0x23
PCF8574 pcf8574(EXPANDER_ADDESS);

HardwareSerial DriverPort( 1 );

/**
 * @brief process the rotary encoders periodically 1ms
 * periodicTicker.attach_ms(1, timer_isr);
 * 
*/
void timer_isr() {
    for (int i=0; i< MAX_ROTARIES; i++) {
        encoders[i]->service();
    }
}


/**
 * @brief check if the signal has a keyboard mapping defined. Don't count the selector mode.
 * 
 * @param signal_num 
 * @return uint8_t 0 if not, else the value of the key being pressed.
*/

uint8_t keyboard_mapping(uint8_t signal_num) {
    uint8_t value = BUTTON_MAP[signal_num];
    // use only fixed buttons to map keyboards,
    // not use mode selector buttons.
    return ( value == 0 || value >  LAST_FIXED_BUTTON ? 0 : KEYBOARD_MAP[value] );
    
}


/**
 * @brief do the buttom mapping using the selector.
 * 
 * first 23 buttons are constant (all the switches, pushbuttons and the ROT5 encoder (topmost))
 * lower rotary are changed based on selector.
 * with 23 + 12 (first 23 buttons + 12 buttons from ROTENCS) I have 8 available modes (with 8 buttons left)
 * so I will limit the rotary encoder using the hardware washer to allow only 8 modes, (losing 9, 10, 11) and
 * map the buttons. so
 * 
 * @param signal_num 
 * @return uint8_t 
*/
uint8_t button_mapping(uint8_t signal_num) {
    uint8_t button_map = BUTTON_MAP[signal_num];

    if (button_map > LAST_FIXED_BUTTON && button_map < FIRST_MODE_BUTTON) {
        button_map = button_map + ((SELECTOR - 1) * 12);
    }
    return button_map;
}


/**
 * @brief send buttons to the BL device.
 * 
*/
void send_buttons() {

    #ifdef TESTING
    if (true) {
    #else
    if (bleDevice.isConnected()) {
    #endif

        for (uint8_t i=0; i<MAX_SIGNALS; i++) {
            uint8_t button_value = SIGNALS[i];
            uint8_t button_map = button_mapping(i);
            #ifdef ENABLE_KEYBOARD_MAP
                uint8_t key_map = keyboard_mapping(i);
            #endif
            if (button_map == 0) {
                continue;
            }

            if (button_value) {
                #if !defined(RELEASE) && (DEBUG & DEBUG_BUTTON)
                memset(line, 0, LINE_SIZE);
                sprintf(line, "Button press %d [selector: %x]", button_map, SELECTOR);
                Serial.println(line);
                if (key_map) {
                    memset(line, 0, LINE_SIZE);
                    sprintf(line, "Button press %d key_press %d", button_map, key_map);
                    Serial.println(line);
                }
                #endif
                
                #ifndef TESTING
                    Gamepad.press(button_map);
                    #ifdef ENABLE_KEYBOARD_MAP
                    if (key_map != 0) {
                        //
                        #ifdef KEYBOARD_CHORD
                            Keyboard.press(KEY_RIGHT_ALT);
                            Keyboard.press(KEY_RIGHT_CTRL);
                        #endif
                        Keyboard.press(key_map);
                        Keyboard.releaseAll();
                    }
                    #endif
                #endif

                

            }
            else {
                #if !defined(RELEASE) && (DEBUG & DEBUG_BUTTON)
                memset(line, 0, LINE_SIZE);
                sprintf(line, "Button release %d [selector: %x]", button_map, SELECTOR);
                Serial.println(line);
                if (key_map) {
                    memset(line, 0, LINE_SIZE);
                    sprintf(line, "Button release %d key_press %d", button_map, key_map);
                    Serial.println(line);
                }                
                #endif
                #ifndef TESTING
                    Gamepad.release(button_map);
                    // not needed, only send the keyboard press and release them quickly
                    // #ifdef ENABLE_KEYBOARD_MAP
                    // if (key_map != 0) {
                    //     #ifdef KEYBOARD_CHORD
                    //         Keyboard.release(KEY_RIGHT_ALT);
                    //         Keyboard.release(KEY_RIGHT_CTRL);
                    //     #endif
                    //     Keyboard.release(key_map);
                    // }
                    // #endif
                #endif
            }
        }
        // I could use the POVS to map additional buttons.
        #ifndef TESTING
            Gamepad.setAxes(0, 0, 0, 0, 0, 0, 0, 0, DPAD_CENTERED, DPAD_CENTERED, DPAD_CENTERED, DPAD_CENTERED);
            //Gamepad.sendAllButtons();
        #endif
    }
}

/**
 * @brief handler for manage a button press in the keypad
 * 
 * @param key 
*/
void pressKey(uint8_t key) {
    #if (!defined(RELEASE) && (DEBUG & DEBUG_KEYS))
        memset(line, 0, LINE_SIZE);
        sprintf(line,"key pressed: %d", key);
        Serial.println(line);
    #endif
    SIGNALS[keymap_signals[key]] = 1;
}

/**
 * @brief handler for manage a button release in the keypad
 * 
 * @param key 
*/
void releaseKey(uint8_t key) {
    #if (!defined(RELEASE) && (DEBUG & DEBUG_KEYS))
        memset(line, 0, LINE_SIZE);
        sprintf(line,"key released: %d", key);
        Serial.println(line);
    #endif
    SIGNALS[keymap_signals[key]] = 0;
}


/**
 * @brief manage the keypad event
 * 
 * @param key 
*/
void keypadEvent(KeypadEvent key) {
    uint8_t keystate = customKeypad.getState();
    if (keystate == PRESSED) {
        pressKey(key);
        
    }
    if (keystate == RELEASED) {
        releaseKey(key);
    }
}


#if !defined(RELEASE) && (DEBUG & DEBUG_SIGNALS)
/**
 * @brief print the signal contents to debug
 * 
*/
void print_signals() {
    Serial.println("\n----------------------------");
    for (int i=0; i<MAX_SIGNALS; i++) {
        memset(line, 0, LINE_SIZE);
        sprintf(line, "SIGNAL_%d: %d", i, SIGNALS[i]);
        Serial.println(line);
    }
}
#endif












/**
 * @brief setup the things. Check the delay to wait for the arduino
 * 
*/
void setup() {
    #ifndef RELEASE
    Serial.begin (115200);
    Serial.println("BL-Radio Started");
    #endif
    // serial port
    delay(1000);
    DriverPort.begin(SERIAL_SPEED, SERIAL_8N1, PIN_RX, PIN_TX );
    


    
    // switches
    pinMode(PIN_SW1_1_S1,INPUT_PULLUP);
    pinMode(PIN_SW1_2_S1,INPUT_PULLUP);
    pinMode(PIN_SW1_3_S1,INPUT_PULLUP);
    pinMode(PIN_SW1_4_S1,INPUT_PULLUP);
    pinMode(PIN_SW1_5_S1,INPUT_PULLUP);
    pinMode(PIN_SW1_6_S1,INPUT_PULLUP);

    // encoders
    encoders[ROT1] = new RotaryEncoder(&pcf8574, P0, P1, -1);  // reversed, so change wires [due bad soldering]
    encoders[ROT2] = new RotaryEncoder(&pcf8574, P2, P3, -1);
    encoders[ROT3] = new RotaryEncoder(&pcf8574, P4, P5, -1);
    encoders[ROT4] = new RotaryEncoder(&pcf8574, P6, P7, -1); 
    encoders[ROT5] = new RotaryEncoder(ROT5_PINA, ROT5_PINB, -1); // reversed, so change wires [due bad soldering]

    //
    // Set low latency with this method or uncomment LOW_LATENCY define in the library
    // Needed for i2c encoders
    pcf8574.setLatency(0);
    // Start library
    
    if (pcf8574.begin()){
        #ifndef RELEASE	  
        Serial.println("pcf8574 lib ok");
        #endif
    }else{
        #ifndef RELEASE	  
        Serial.println("pcf8574 lib ko");
        #endif
    }

    // the bluetooth things
    #ifndef TESTING
        Keyboard.begin();
        Mouse.begin();
        Gamepad.begin();
    #endif


    periodicTicker.attach_ms(1, timer_isr);

    // selector init mode
    SELECTOR = 1;
    PREV_SELECTOR = 0;

    // the keypad matrix
    customKeypad.addEventListener(keypadEvent);

    // the computer takes some time to work
    // so wait here before all the BLE is working
    //

}
















/**
 * @brief do the things. First, save the state, then read form the
 * serial port (selector, some switches) and then build the object
 * and send it using BLE. 
 * 
*/


#define DELAY_PERIOD 2000 
unsigned long timestamp = millis();
bool waitting_delay = true;

void loop() {

    waitting_delay = true;
    if (millis() - timestamp > DELAY_PERIOD) {
        waitting_delay = false;
        timestamp = millis();
    }

    //
    // read the keypad custom matrix for  buttons
    // 
    customKeypad.getKey();  

    // 
    // read the data from serial This must be encapsulated in a function.
    // 

    if ( DriverPort.available() ) {
        DATA = DriverPort.read();
        SIGNALS[S_SW2_2_S2] = ( (DATA >> 4) & 1UL ? 1 : 0);
        SIGNALS[S_SW2_2_S1] = ( (DATA >> 5) & 1UL ? 1 : 0);
        SIGNALS[S_SW2_1_S2] = ( (DATA >> 6) & 1UL ? 1 : 0);
        SIGNALS[S_SW2_1_S1] = ( (DATA >> 7) & 1UL ? 1 : 0);
        uint8_t SELECTOR_value = DATA & 15; // lower value;
        SELECTOR = SELECTOR_value;

        for (int i=0; i< MAX_MODES; i++) {
            unsigned char signal_id = mode_map[i];
            unsigned char signal_value = ( SELECTOR-1 == i ? 1 : 0 );
            SIGNALS[signal_id] = signal_value;
        }

        #if !defined(RELEASE) && (DEBUG & DEBUG_SERIAL)
            memset(line,0, LINE_SIZE);
            sprintf(line,"data: %x", DATA);
            Serial.println(line);
        #endif
    }

    // 
    // read the switches
    //
    SIGNALS[S_SW1_1_S1] = ( digitalRead(PIN_SW1_1_S1) == 0 ? 0 : 1 );
    SIGNALS[S_SW1_2_S1] = ( digitalRead(PIN_SW1_2_S1) == 0 ? 0 : 1 );
    SIGNALS[S_SW1_3_S1] = ( digitalRead(PIN_SW1_3_S1) == 0 ? 0 : 1 );
    SIGNALS[S_SW1_4_S1] = ( digitalRead(PIN_SW1_4_S1) == 0 ? 0 : 1 );
    SIGNALS[S_SW1_5_S1] = ( digitalRead(PIN_SW1_5_S1) == 0 ? 0 : 1 );
    SIGNALS[S_SW1_6_S1] = ( digitalRead(PIN_SW1_6_S1) == 0 ? 0 : 1 );

    for (int i=0; i< MAX_ROTARIES; i++) {

        switch (encoders[i]->getDirection()) {
            case RotaryEncoder::RIGHT:
                #if !defined(RELEASE) && (DEBUG & DEBUG_ROTENC)
                    memset(line, 0, 128);
                    sprintf(line,"encoder #%d CW (Right)", i+1);
                    Serial.println(line);
                #endif
                SIGNALS[rotenc_map[i][ROT_RIGHT]] = 1;
                break;
            case RotaryEncoder::LEFT:
                #if !defined(RELEASE) && (DEBUG & DEBUG_ROTENC)
                    memset(line, 0, 128);
                    sprintf(line,"encoder #%d CCW (Left)", i+1);
                    Serial.println(line);
                #endif
                SIGNALS[rotenc_map[i][ROT_LEFT]] = 1;
                break;
            default:
                SIGNALS[rotenc_map[i][ROT_LEFT]] = 0;
                SIGNALS[rotenc_map[i][ROT_RIGHT]] = 0;
                break;
        }
    }
    

    
    // send the things here
    if ((memcmp(PREV_SIGNALS, SIGNALS, MAX_SIGNALS) != 0) || (SELECTOR != PREV_SELECTOR) || (!waitting_delay)) {
        #if !defined(RELEASE) && (DEBUG & DEBUG_SIGNALS)
        print_signals();
        #endif
        send_buttons();
        PREV_SELECTOR = SELECTOR;
        memcpy(PREV_SIGNALS, SIGNALS, MAX_SIGNALS);
    }


}

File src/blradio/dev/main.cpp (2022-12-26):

//////////////////////////////////////////////////////////////////////////////
///
/// @file i2cenc.ino
/// @author Juan M. Casillas (juanm.casillas@gmail.com)
/// @brief test the PCF8574 and encoder lib
/// @version 0.1
/// @date 2022/12/22
///
/// Code to test the PCF8574 expansor and some features.
/// P0 is the pin nearest the address jumpers.
/// 
/// @copyright Copyright (c) 12/22/2022 Juan M. Casillas <juanm.casillas@gmail.com>
///
//////////////////////////////////////////////////////////////////////////////
// PCF8574
// https://www.luisllamas.es/mas-pines-digitales-con-arduino-y-el-expansor-es-i2c-pcf8574/
// use this https://github.com/xreef/PCF8574_library/releases
// https://github.com/khoih-prog/ESP32TimerInterrupt
//
// 32 (0x20)
// default jumper connection:
// 32 (0x20) address
// x x x
// x x x
// | | | 
// x x x
//A0   A2
//
// 33 (0x21) address
// x x x
// |
// x x x
//   | | 
// x x x
//A0   A2
//
// 35 (0x23) address
// x x x
// | |
// x x x
//     |  
// x x x
//A0   A2
//

// our working example
//
// 35 (0x23) address
// x x x
// | |
// x x x
//     |  
// x x x
//A0   A2
//

// P0 -> push_button
// P1 -> push_button
// P2 -> push_button

// P3 -> SW
// P4 -> DT
// P5 -> CLK


// #define RELEASE 1
//#define DEBUG 1

#include <Arduino.h>
#include <PCF8574.h>
#include <Ticker.h>
#include <HardwareSerial.h>
#include "rotencoder.h"
#include "bltools.h"


Ticker periodicTicker;


#define EXPANDER_ADDESS 0x23
PCF8574 pcf8574(EXPANDER_ADDESS);



HardwareSerial DriverPort( 1 );
#define PIN_RX 27
#define PIN_TX 26


//
// unsigned char INPUT_PINS[] = {  0,  0,  2,  3,  4,  5,  6,  7, 
//                                 0,  0, 10, 11, 12,  0, A0, A1, 
//                                A2, A3, A4, A5,  0 , 0,  0,  0 ,
//                                 0,  0,  0,  0,  0 , 0,  0,  0  };
//
// SIGNALS [NANO]
// [2] = 1P12T_1
// [3] = 1P12T_2
// [4] = 1P12T_3
// [5] = 1P12T_4
// [6] = 1P12T_5
// [7] = 1P12T_6
// [10] = 1P12T_7
// [11] = 1P12T_8
// [12] = 1P12T_9
// [14] = 1P12T_10
// [15] = 1P12T_11
// [16] = SW2_1_S1
// [17] = SW2_1_S2
// [18] = SW2_2_S1
// [19] = Sw2_2_S2

#define S_1P12T_1    0
#define S_1P12T_2    1
#define S_1P12T_3    2
#define S_1P12T_4    3
#define S_1P12T_5    4
#define S_1P12T_6    5
#define S_1P12T_7    6
#define S_1P12T_8    7
#define S_1P12T_9    8
#define S_1P12T_10   9
#define S_1P12T_11  10

#define S_SW2_1_S1  11
#define S_SW2_1_S2  12
#define S_SW2_2_S1  13
#define S_SW2_2_S2  14

#define S_SW1_6_S1  15  // G2
#define S_SW1_5_S1  16  // G4
#define S_SW1_4_S1  17  // G5
#define S_SW1_3_S1  18  // G12
#define S_SW1_2_S1  19  // G14
#define S_SW1_1_S1  20  // G15

// rotary definitions
#define MAX_ROTARIES 5
RotaryEncoder *encoders[MAX_ROTARIES];
#define ROT5_PINA 35
#define ROT5_PINB 34
#define ROT1    0
#define ROT2    1
#define ROT3    2
#define ROT4    3
#define ROT5    4


unsigned char SIGNALS[21] = {0};



//
// refresh the encoders to get the value.
//
void timer_isr() {
    for (int i=0; i< MAX_ROTARIES; i++) {
        encoders[i]->service();
    }
}



void setup() {
    #ifndef RELEASE	  
    Serial.begin (115200);
    Serial.println("i2cTEST Started");
    #endif
    // serial port
    DriverPort.begin(SERIAL_SPEED, SERIAL_8N1, PIN_RX, PIN_TX );
    delay(500);


    // PINS ARE SWAPPED IN ORDER TO WORK IN THE WIRE.
    // p3 connected to wire B
    // p4 connected to wire A
    // if you invert the wires, doesn't work. Check it.

    // define the 6 encoders. 
    // CLK(A), DT(B), SW
    encoders[ROT1] = new RotaryEncoder(&pcf8574, P1, P0, -1);
    encoders[ROT2] = new RotaryEncoder(&pcf8574, P2, P3, -1);
    encoders[ROT3] = new RotaryEncoder(&pcf8574, P4, P5, -1);
    encoders[ROT4] = new RotaryEncoder(&pcf8574, P6, P7, -1);
    encoders[ROT5] = new RotaryEncoder(ROT5_PINB, ROT5_PINA, -1);

    //pinMode(ROT5_PINA,INPUT_PULLUP);
    //pinMode(ROT5_PINB,INPUT_PULLUP);

    // Interval in microsecs
    // Set low latency with this method or uncomment LOW_LATENCY define in the library
    // Needed for encoder

    pcf8574.setLatency(0);
    // Start library
    #ifndef RELEASE	  
    if (pcf8574.begin()){
        Serial.println("pcf8574 lib ok");
    }else{
        Serial.println("pcf8574 lib ko");
    }
    #endif
    
    periodicTicker.attach_ms(1, timer_isr);

}



long prev_value = 0;

void loop() {

    PREV_BUTTONS = BUTTONS;

    // 
    // read the data from serial This must be encapsulated in a function.
    // 
    if ( DriverPort.available() >= PACKET_SIZE ) {
        uint8_t data[6]; // size of serial_package_s;

        for (int i=0; i< PACKET_SIZE; i++) {
            data[i] = DriverPort.read();
        }
        PACKET.header = data[0];
        PACKET.data   = data[1] | (data[2] << 8) | (data[3] << 16) | (data[4] << 24);
        PACKET.footer = data[5];

        if (PACKET.header == 0xDE && PACKET.footer == 0xAD) {
            BUTTONS = PACKET.data;
        }
        else {
            // some problem with the serial port.
        }
    }

    if (PREV_BUTTONS != BUTTONS) {
        #ifndef RELEASE
        print_state();
        #endif
    }

    // the IC part here.
    //uint8_t p0 = pcf8574.digitalRead(ROT5_PINA);
    //uint8_t p1 = pcf8574.digitalRead(ROT5_PINB);
    //uint8_t p2 = pcf8574.digitalRead(P2);
    //uint8_t p6 = pcf8574.digitalRead(P6);
    //uint8_t p7 = pcf8574.digitalRead(P7);
    //p0 = ( p0 == 0 ? 1 : 0); // not wired
    //p1 = ( p1 == 0 ? 1 : 0);
    //p2 = ( p2 == 0 ? 1 : 0); 
    //p6 = ( p6 == 0 ? 1 : 0); 
    // p7 = ( p7 == 0 ? 1 : 0); 

    // not connected in hw
    // if (p0) {
    //     memset(line, 0, 128);
    //     sprintf(line,"button pressed: %d, [GPIO %d]", 0, P0);
    //     Serial.println(line);
    // }
    // if (p1) {
    //     memset(line, 0, 128);
    //     sprintf(line,"button pressed: %d, [GPIO %d]", 1, P1);
    //     Serial.println(line);
    // }
    // if (p2) {
    //     memset(line, 0, 128);
    //     sprintf(line,"button pressed: %d, [GPIO %d]", 2, P2);
    //     Serial.println(line);
    // }
    // if (p6) {
    //     memset(line, 0, 128);
    //     sprintf(line,"button pressed: %d, [GPIO %d]", 6, P6);
    //     Serial.println(line);
    // }
    // if (p7) {
    //     memset(line, 0, 128);
    //     sprintf(line,"button pressed: %d, [GPIO %d]", 7, P7);
    //     Serial.println(line);
    // }

    for (int i=0; i< MAX_ROTARIES; i++) {
        if (encoders[i]->getButton() == RotaryEncoder::PRESSED) {
            #ifndef RELEASE
                memset(line, 0, 128);
                sprintf(line,"encoder #%d button pressed", i+1);
                Serial.println(line);
            #endif
        }
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

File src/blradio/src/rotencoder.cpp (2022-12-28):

//////////////////////////////////////////////////////////////////////////////
///
/// @file rotencoder.cpp
/// @author Juan M. Casillas (juanm.casillas@gmail.com)
/// @brief implementation file
/// @version 0.1
/// @date 2022/12/22
///
///  
/// 
/// @copyright Copyright (c) 12/22/2022 Juan M. Casillas <juanm.casillas@gmail.com>
///
//////////////////////////////////////////////////////////////////////////////

#include "rotencoder.h"

/**
 * @brief Construct a new Rotary Encoder:: Rotary Encoder object. Local wired version
 * 
 * @param A 
 * @param B 
 * @param BTN 
 * @param active 
*/
RotaryEncoder::RotaryEncoder(uint8_t A, uint8_t B, int BTN, bool active) {
    i2c_exp = NULL;
    this->BaseConstructor(A, B, BTN, active);
    //this->pinMode(pinA,   configType);
    //this->pinMode(pinB,   configType);
    ESP32Encoder::useInternalWeakPullResistors=UP;
    this->_encoder.attachHalfQuad(pinA, pinB);
    if (pinBTN>=0) {
        this->pinMode(pinBTN, configType); 
        previous_button = this->digitalRead(pinBTN);
    }
      

}

/**
 * @brief Construct a new Rotary Encoder:: Rotary Encoder object. PCF8574 i2c expansor
 * 
 * @param _i2c_exp 
 * @param A 
 * @param B 
 * @param BTN 
 * @param active 
*/

RotaryEncoder::RotaryEncoder(PCF8574 *_i2c_exp, uint8_t A, uint8_t B, int BTN, bool active) {
    i2c_exp = _i2c_exp;
    this->BaseConstructor(A, B, BTN, active);
    i2c_exp->encoder(A,B);
    if (pinBTN>=0) {
        this->pinMode(pinBTN, configType); 
        previous_button = this->digitalRead(pinBTN);
    }

}

/**
 * @brief this function should be called periodically
 * 
 *  For example, using Ticker library:
 *  #include <Ticker.h>
 *  Ticker periodicTicker;
 * void timer_isr() {
 *   for (int i=0; i< MAX_ROTARIES; i++) {
 *       encoders[i]->service();
 *   }
 * }
 * periodicTicker.attach_ms(1, timer_isr);
*/
void RotaryEncoder::service() {

    if (i2c_exp != NULL) {
        changed = i2c_exp->readEncoderValue(pinA, pinB, &value);
    } else {
        value = _encoder.getCount();
    }

    if (pinBTN>=0) {
        uint8_t current_state_c = this->digitalRead(pinBTN); // BTN
        if (current_state_c!=previous_button){
        previous_button = current_state_c;
        button = (current_state_c == active_config ? RotaryEncoder::PRESSED  : RotaryEncoder::NONE);
        }
    }

    // cleanup the first time
    if (first_time) {
        changed = false;
        value = 0;
        previous_value = 0;
        first_time = 0;
    }


}

// protected functions

/**
 * @brief base constructor.
 * 
 * @param A 
 * @param B 
 * @param BTN 
 * @param active 
*/
void RotaryEncoder::BaseConstructor(uint8_t A, uint8_t B, int BTN, bool active) {
    pinA = A;
    pinB = B;
    pinBTN = BTN;
    active_config = active;

    configType = ((active_config == LOW) ? INPUT_PULLUP : INPUT);
    changed = false;
    button = RotaryEncoder::NONE;
    value = 0;
    previous_button  = 0;
    previous_value   = 0;

}

/**
 * @brief wrapper about digitalRead, to use the i2c or local one
 * 
 * @param pin 
 * @return uint8_t 
*/
uint8_t RotaryEncoder::digitalRead(uint8_t pin) {
    if (i2c_exp) {
        return i2c_exp->digitalRead(pin);
    }
    return ::digitalRead(pin);
}

/**
 * @brief wrapper about pinMode, to use the i2c or local one
 * 
 * @param pin 
 * @param mode 
*/
void RotaryEncoder::pinMode(uint8_t pin, uint8_t mode) {
    if (i2c_exp) {
        i2c_exp->pinMode(pin, mode);
        return;
    }
    ::pinMode(pin, mode);
}

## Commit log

2020-09-08 Initial working release with BLE
    See electrical layout. We need pull_up resistors and check the way the pins are connected
2020-09-11 Fixed the delay to avoid hangs
    [blbuttons.ino]
2020-09-12 Added PIN documentation
2020-09-14 Added the state support, so axis are not reset if the mode changes.
    [blbuttons.ino]
2020-09-14 Initial wiring and testing. All buttons working (matrix also)
2020-09-15 Added a filter function for the analog read, so they become much more stable. Works fine. Also some hippcus on Mac with BT connect/disconnect, but works perfect on WIN10
2020-09-16 Removed unused software Added building pics Added cover.stl (for 3dPrint)
    [cover.stl]
2020-09-16 Removed System.print() and reformat code.
2022-12-13 added support for multi device in BL (keyboard, mouse and gamepad)
2022-12-13 Added support for Keyboard & Mouse devices under BL
2022-12-21 added the test for the new system
    [Multi-Button Resistor Ladder Calculator.xlsx]
2022-12-21 fixed the serial protocol
    [espreader.ino, nanowriter.ino]
2022-12-22 added support for i2c (scan and read) fixed the clickencode library, added timer
    [i2cscan.ino]
2022-12-22 added a fully working demo (serial + i2c)
2022-12-22 added support for normal rotary encoder (directly attached, may need rework
    [rotencoder.cpp]
2022-12-23 added the rotary to the arduino nano and get it working with the system
2022-12-24 added wiring map, added pics
2022-12-25 added the wiring diagram
2022-12-27 added documentation about buttons, all code more or less stable with selector working
2022-12-29 fixed a wiring mapping in the 2way switches
    [main.cpp]
2022-12-29 fixed a problem sending the buttons
    [main.cpp]
2022-12-29 fixed some problems with signal 11
    [main.cpp]
2022-12-29 fixed a typo in rotary encoder button
2022-12-30 fixed some problems in the rotenc mapping, added some performance improvement. Added detailed debug info
    [main.cpp]
2023-01-09 simplify the serial protocol (now only 1 byte) fixed the send button to avoid problems in the delay BLE
    [main.cpp]
2023-01-09 solved changing the power source to USB 5v in arduino nano
    [main.cpp]
2023-01-13 added a simple app to say the commands in the buttons
2023-01-13 added device container for multiple devices
2023-01-13 initial release with multiple device support and toggle ON/OFF for the same button
2023-01-14 added buttons for mode selector, so we can map it to voice commands
2023-01-17 added stl models
    [button_round.stl, button_round_variant.stl, button_square.stl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]
2023-10-05 added keyboard mapping and chord features to double some buttons as keypresses
2023-10-09 Fixed the F8 lines
    [blbuttons.ino]
2023-10-09 fixed the keyboard mapping
    [blbuttons.ino]
2023-10-09 fixed the Fxx problem and upgraded to new version
    [blbuttons.ino]
